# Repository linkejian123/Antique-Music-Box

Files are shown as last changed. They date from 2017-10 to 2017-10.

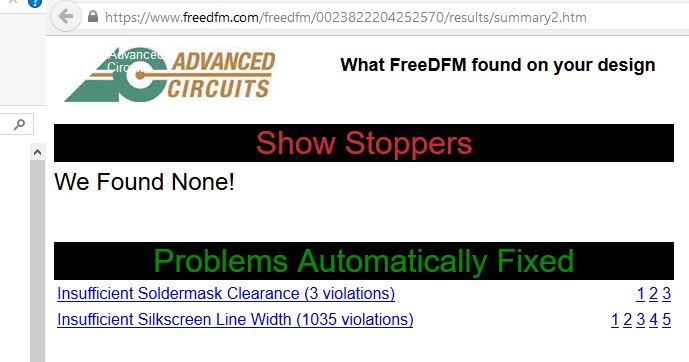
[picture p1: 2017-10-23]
OBJ477/Gerbers/iv17.JPG

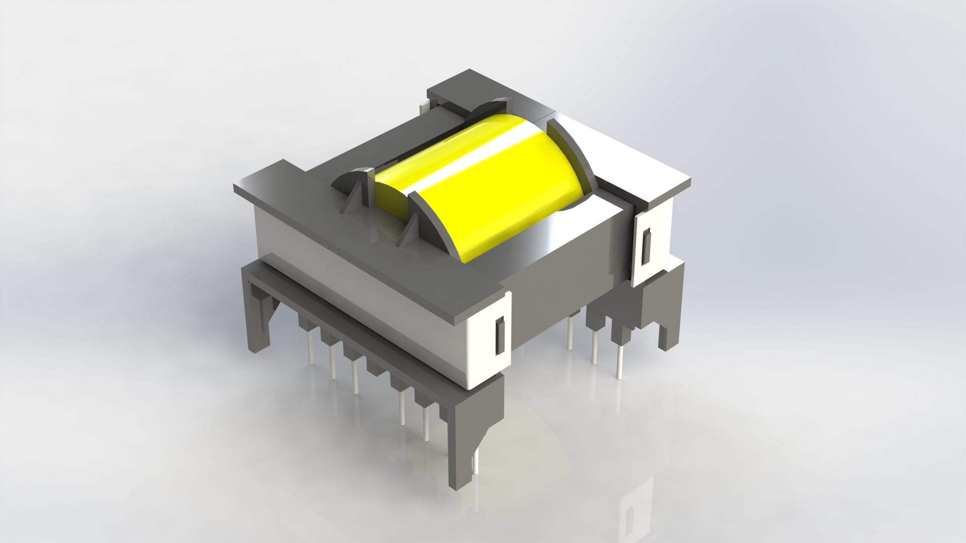
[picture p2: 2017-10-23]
CAD/etd39-transformer-horizontal-1.snapshot.6/Renderings/ETD39 Transformer (Horizontal).JPG

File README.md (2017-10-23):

# Antique-Music-Box

### Description
-This project was originally a senior design project in Purdue University ECE477. 
-This is a music player capable of playing mp3 on SD card or stream Bluetooth music from Android devices. The music box has digital amplifier and valve tube pre-amp. The display used 60s style VFD tube from Soviet era.
-The Microcontroller used is Microchips dsPIC33FJ256GP710A.
- !!!!  Demo Vidoe here:https://www.youtube.com/watch?v=YaUscYTW8Vs&t=1s

### Authors
-Kejian Lin
-Ran An
-Yixing Liu
-Zhiyi Xiang

### Repository Structure

-`main`,`mp3`,`sd`, `AntiqueMB.X` are the code for the PIC microcontroller for main, mp3 and sd card as it states.
- `multithread` is the experimental multithread code.
- `arduino` is the interface code for Arduino Uno.
- `CAD` is the conceptual SolidWorks model for the project.
- `OBJ477` is the PCB files in Eagle. 

### Warning
 #### High voltage
 #### Some hotfix are not documented, yet

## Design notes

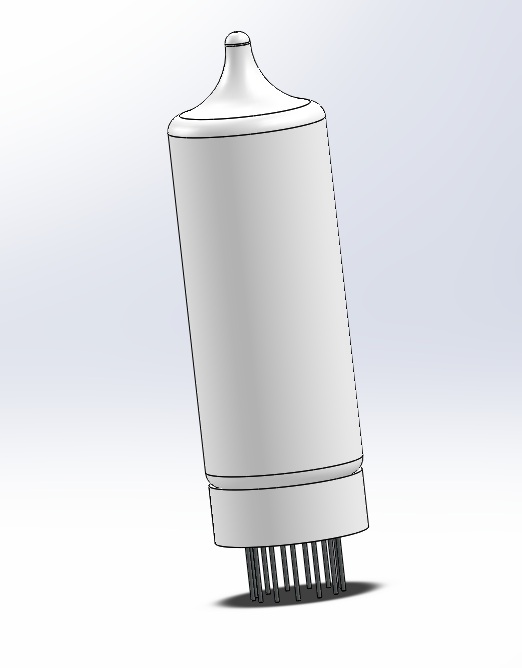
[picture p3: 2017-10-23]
CAD/em84/Renderings/IN-14.jpg

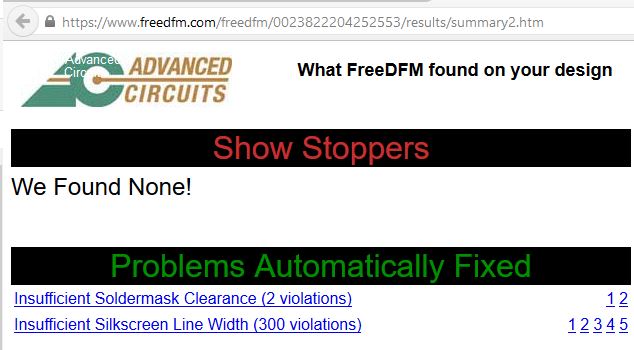
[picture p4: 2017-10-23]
OBJ477/Gerbers/hifi.JPG

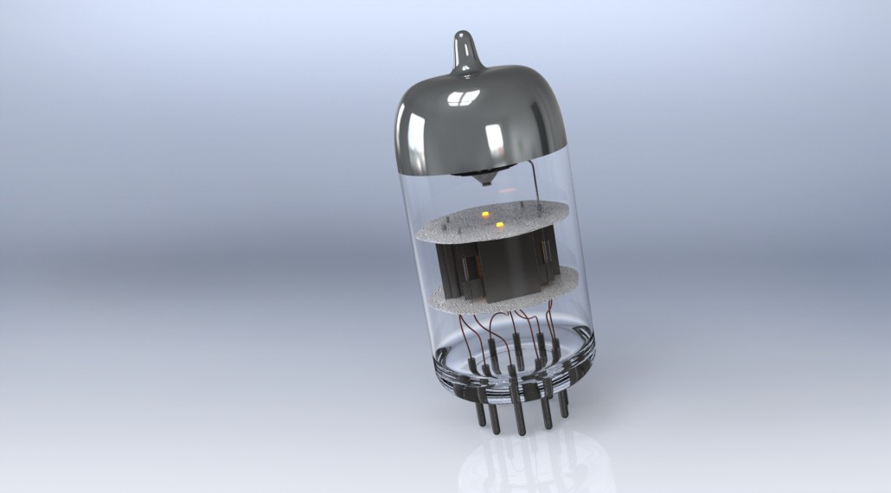
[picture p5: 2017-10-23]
CAD/ecc88/Renderings/ecc88_00220120219-29209-4jer0m.JPG

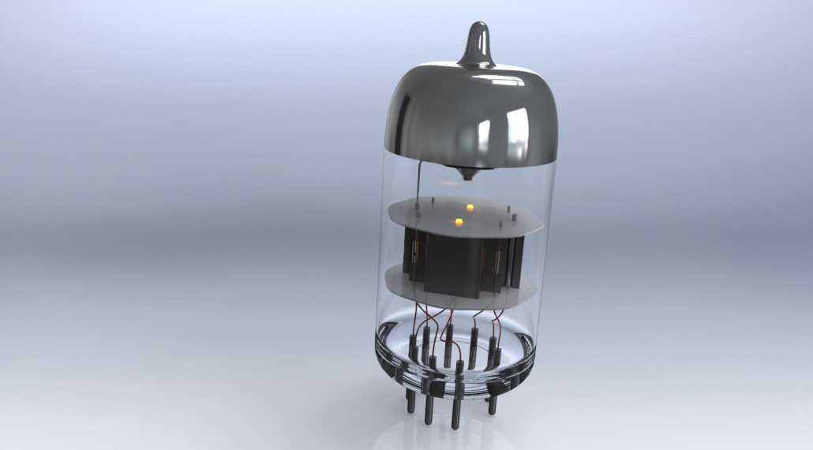
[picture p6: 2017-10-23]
CAD/ecc88/Renderings/ecc88_00120120219-28439-1ot95d6.JPG

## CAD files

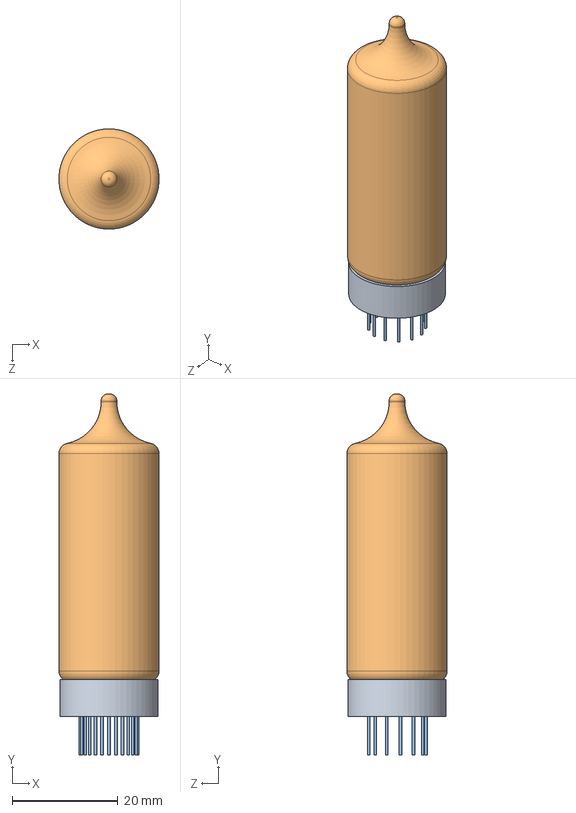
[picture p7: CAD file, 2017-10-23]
CAD/iv-17/IN-14.SLDASM
19.0 x 68.4 x 19.0 mm
pcb_standoff
tube_body
tube_leads
flip

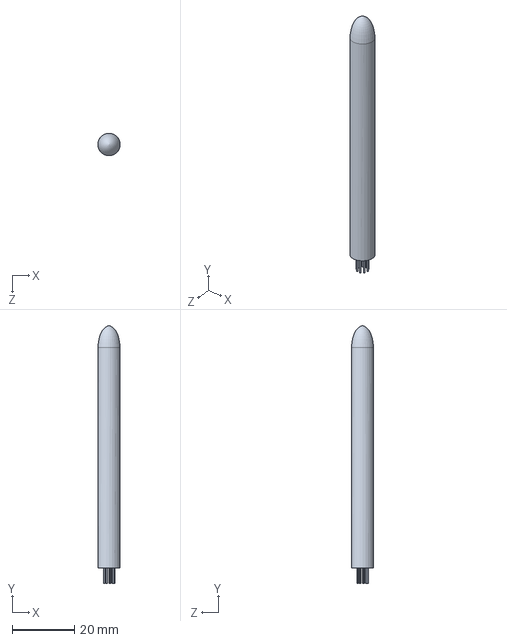
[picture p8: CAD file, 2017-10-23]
CAD/iv-25/vfdbartube.SLDASM
7.20 x 83.0 x 7.20 mm
iv-25
insole

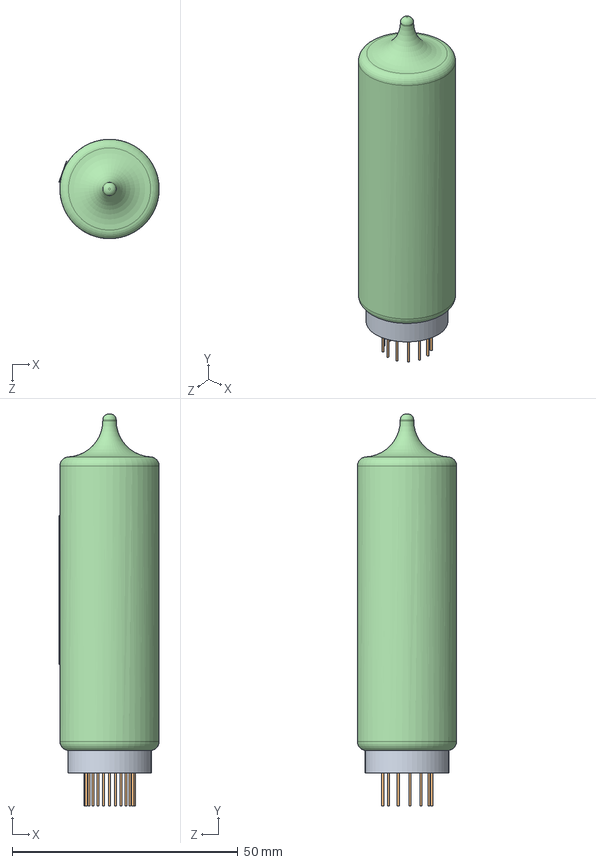
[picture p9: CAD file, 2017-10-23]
CAD/em84/em84.SLDASM
22.2 x 86.8 x 22.0 mm
pcb_standoff
tube_leads
tiepian
tube_body2

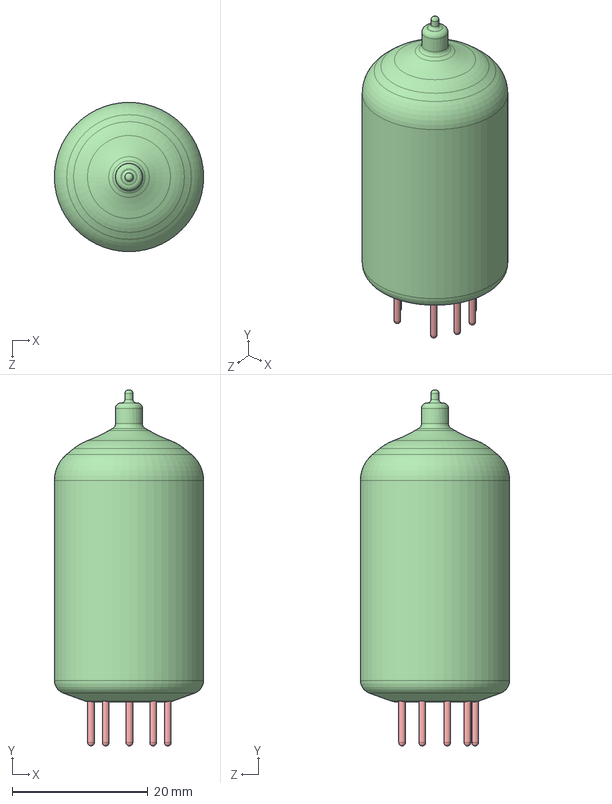
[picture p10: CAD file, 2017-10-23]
CAD/msc/12ax7/12ax7_complete.SLDASM
22.0 x 52.5 x 22.0 mm
mica3_lower
cathode x 2
grid x 2
grid wire x 120
cathode_end x 4
anode x 4
sheild
mica2
support_pin x 4
top_mica
boat
12ax7_glass
pins

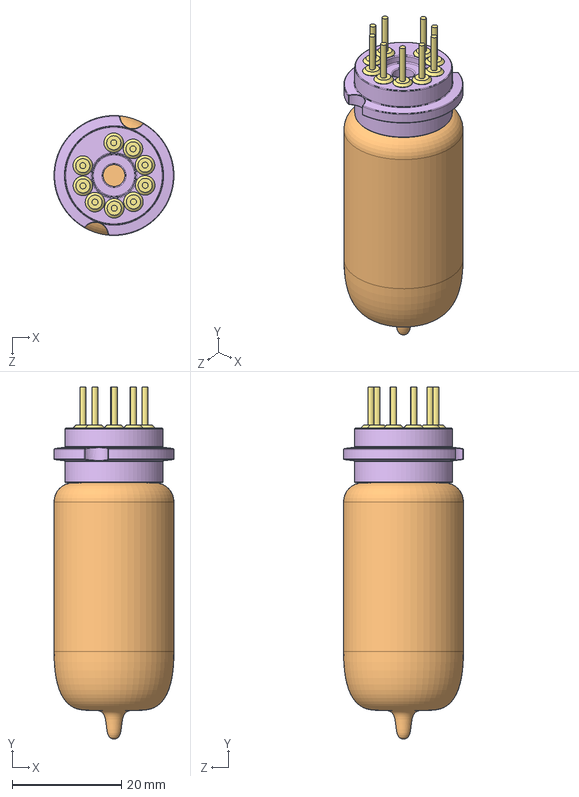
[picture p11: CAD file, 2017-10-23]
CAD/ecc88/ecc88/ECC88.SLDASM
22.0 x 64.5 x 22.0 mm
ecc88_pins
ecc88_balon
ecc88_insulator x 2
ecc88_reflector
ecc88_heater
noval ceramic body
Noval pin x 9

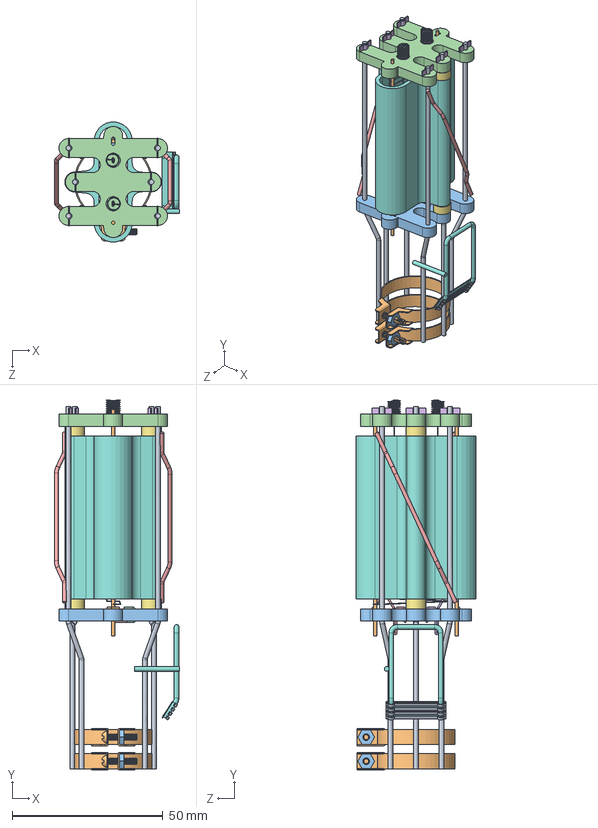
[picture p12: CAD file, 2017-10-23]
CAD/msc/845/845 - INTERNALS.SLDASM
41.5 x 122.6 x 39.8 mm
845 - support rods
845 - support rod clamp x 2
845 - bottom ceramic
845 - centre cathode anchor
845 - left hand cathode anchor
845 - right hand cathode anchor
845 - top ceramic spacer x 4
845 - anode
845 - cathode
845 - grid support x 2
845 - grid wire
845 - top ceramic
845 - suppoty brace x 2
845 - retaining bit x 6
845 - cathode spring x 2
845 - boat frame
845 - boat part 2
845 - little screw x 2
845 - little nut x 2

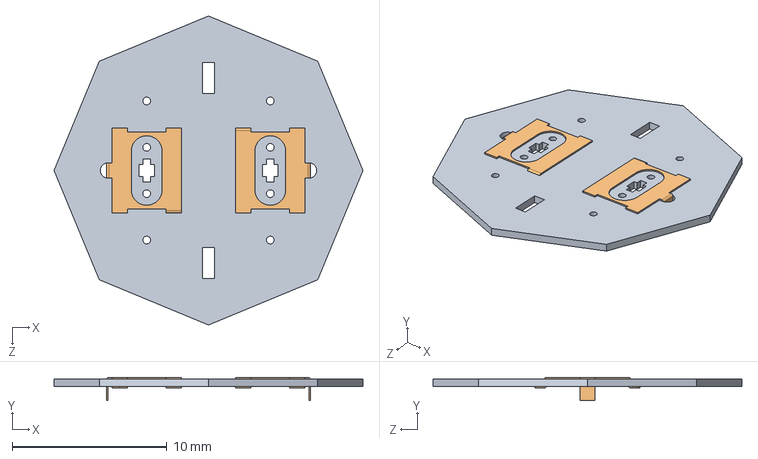
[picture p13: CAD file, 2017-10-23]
CAD/msc/12ax7/12ax7_mica_2.sldasm
20.0 x 1.50 x 20.0 mm
mica2
cathode_end x 2

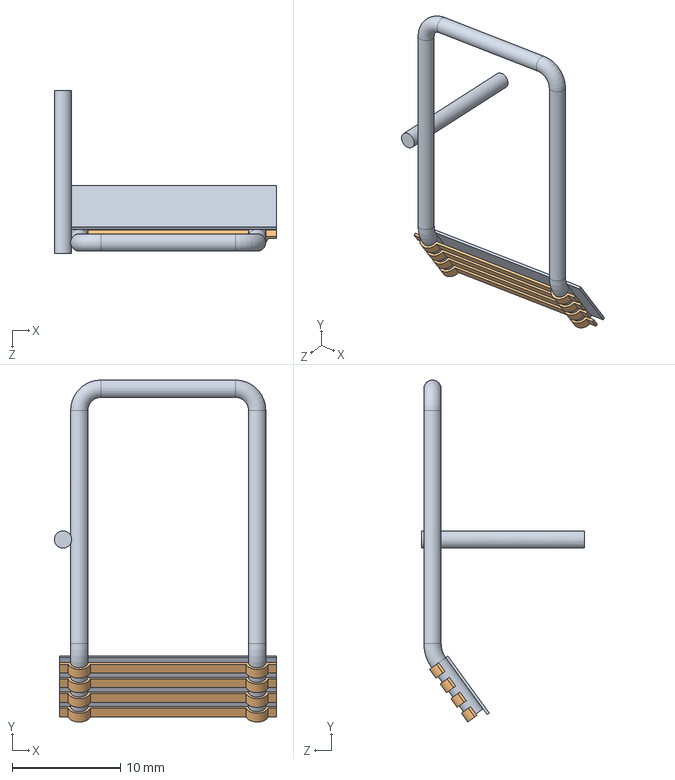
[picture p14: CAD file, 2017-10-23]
CAD/msc/845/845 - BOAT ASSEMBLY.SLDASM
20.5 x 31.5 x 15.0 mm
845 - boat frame
845 - boat part 2

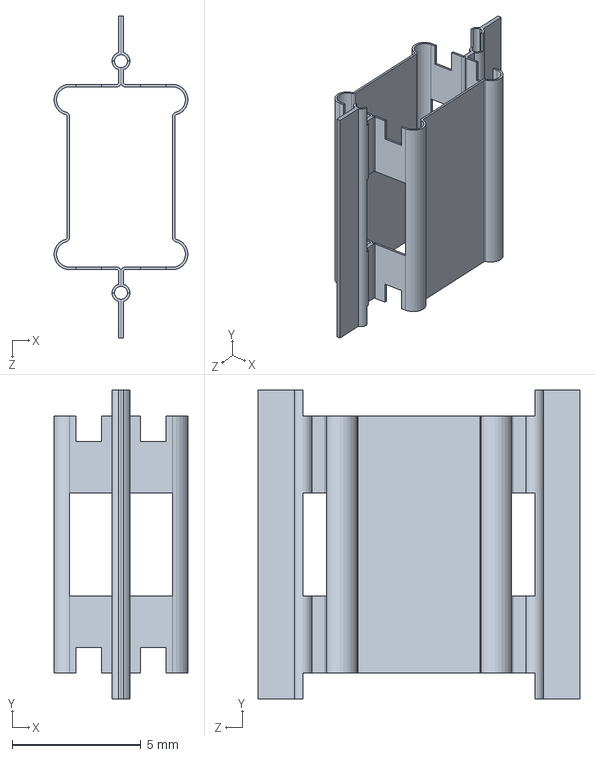
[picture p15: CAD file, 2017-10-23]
CAD/msc/12ax7/anode_assy.sldasm
5.19 x 12.0 x 12.5 mm
anode x 2

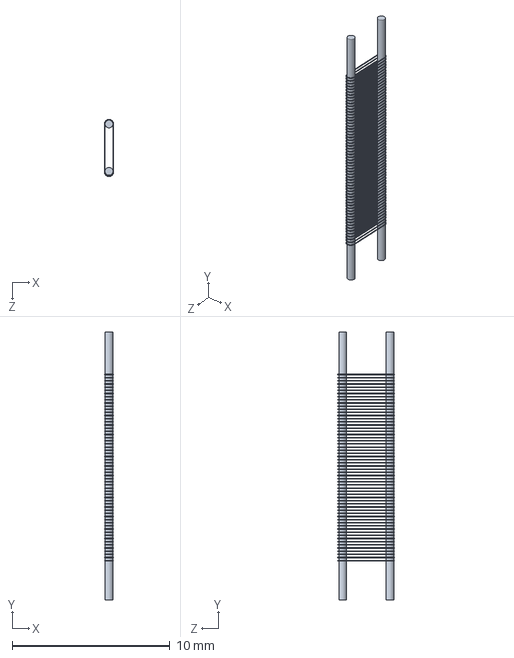
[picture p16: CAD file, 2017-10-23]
CAD/msc/12ax7/grid assembly.SLDASM
0.59 x 17.0 x 3.64 mm
grid
grid wire x 60

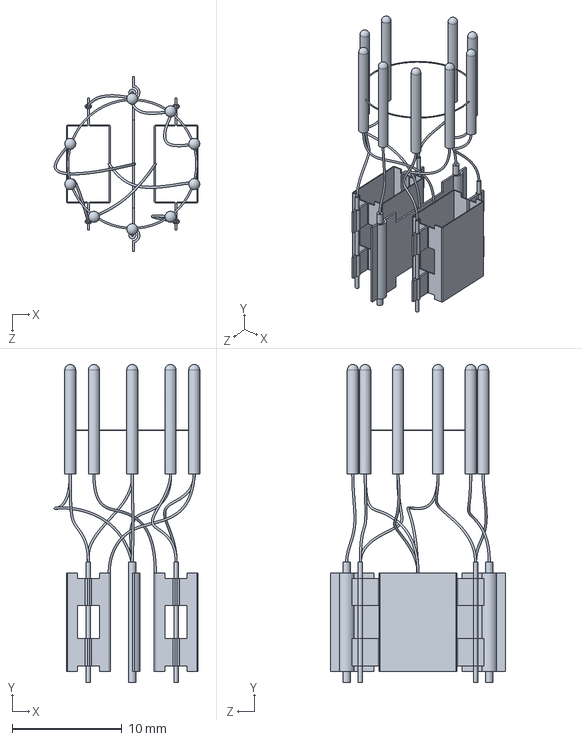
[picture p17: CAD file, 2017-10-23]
CAD/ecc88/ecc88/ecc88_pins.SLDPRT
13.3 x 29.0 x 16.0 mm

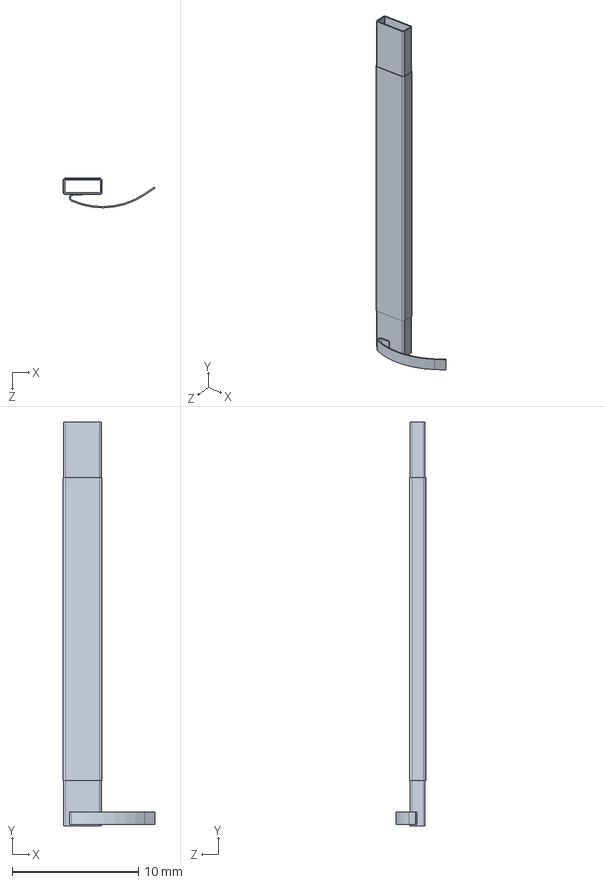
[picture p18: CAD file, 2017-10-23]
CAD/el84 sub 6z4/EL84 CATHODE.SLDPRT
7.28 x 32.0 x 2.35 mm

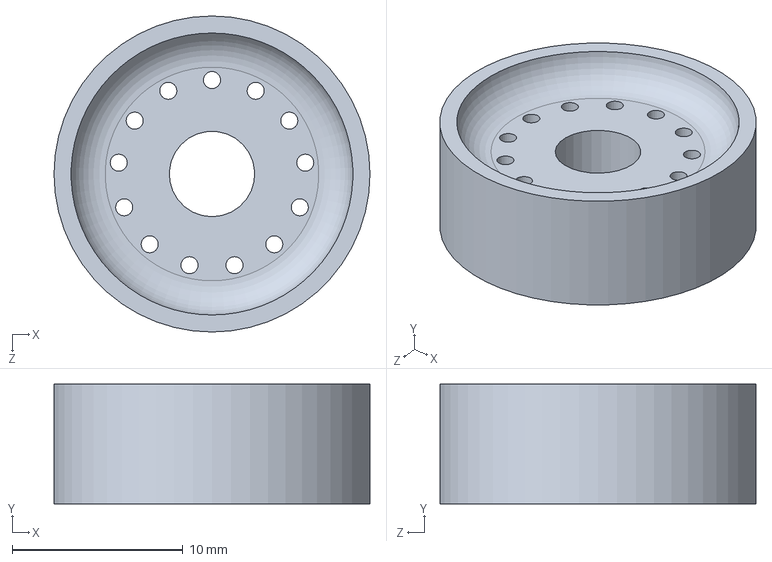
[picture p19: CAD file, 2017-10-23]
CAD/em84/pcb_standoff.SLDPRT
18.5 x 7.00 x 18.5 mm

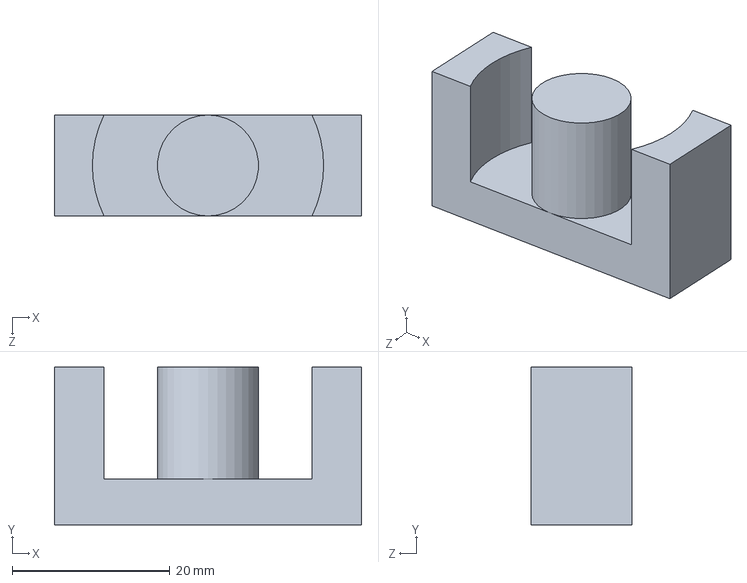
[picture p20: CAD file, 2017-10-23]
CAD/etd39-transformer-horizontal-1.snapshot.6/ETD39 Horizontal/6. Core.SLDPRT
38.9 x 20.0 x 12.8 mm

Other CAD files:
CAD/etd39-transformer-horizontal-1.snapshot.6/ETD39 Horizontal/1. ETD39 assembly.SLDASM
CAD/little-knob.snapshot.2/myknob.IGS
CAD/msc/12ax7/sheild.sldprt
CAD/msc/845/845 - cathode.SLDPRT
CAD/ecc88/ecc88/ecc88_balon.SLDPRT
CAD/ecc88/ecc88/ecc88_heater.SLDPRT
CAD/ecc88/ecc88/ecc88_insulator.SLDPRT
CAD/ecc88/ecc88/ecc88_reflector.SLDPRT
CAD/el84 sub 6z4/EL84 HEATER LEADS.SLDPRT
CAD/el84 sub 6z4/el34 suppressor.SLDPRT
CAD/el84 sub 6z4/el84 - boat.SLDPRT
CAD/el84 sub 6z4/el84 - spring thing.SLDPRT
CAD/el84 sub 6z4/el84 - top shield.SLDPRT
CAD/el84 sub 6z4/el84 glass.SLDPRT
CAD/el84 sub 6z4/el84 lower mica.SLDPRT
CAD/el84 sub 6z4/el84 pins.SLDPRT
CAD/el84 sub 6z4/el84 plate.SLDPRT
CAD/el84 sub 6z4/screen connector.SLDPRT
CAD/em84/tiepian.SLDPRT
CAD/em84/tube_body2.SLDPRT
CAD/em84/tube_leads.SLDPRT
CAD/etd39-transformer-horizontal-1.snapshot.6/ETD39 Horizontal/2. Case (center).SLDPRT
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

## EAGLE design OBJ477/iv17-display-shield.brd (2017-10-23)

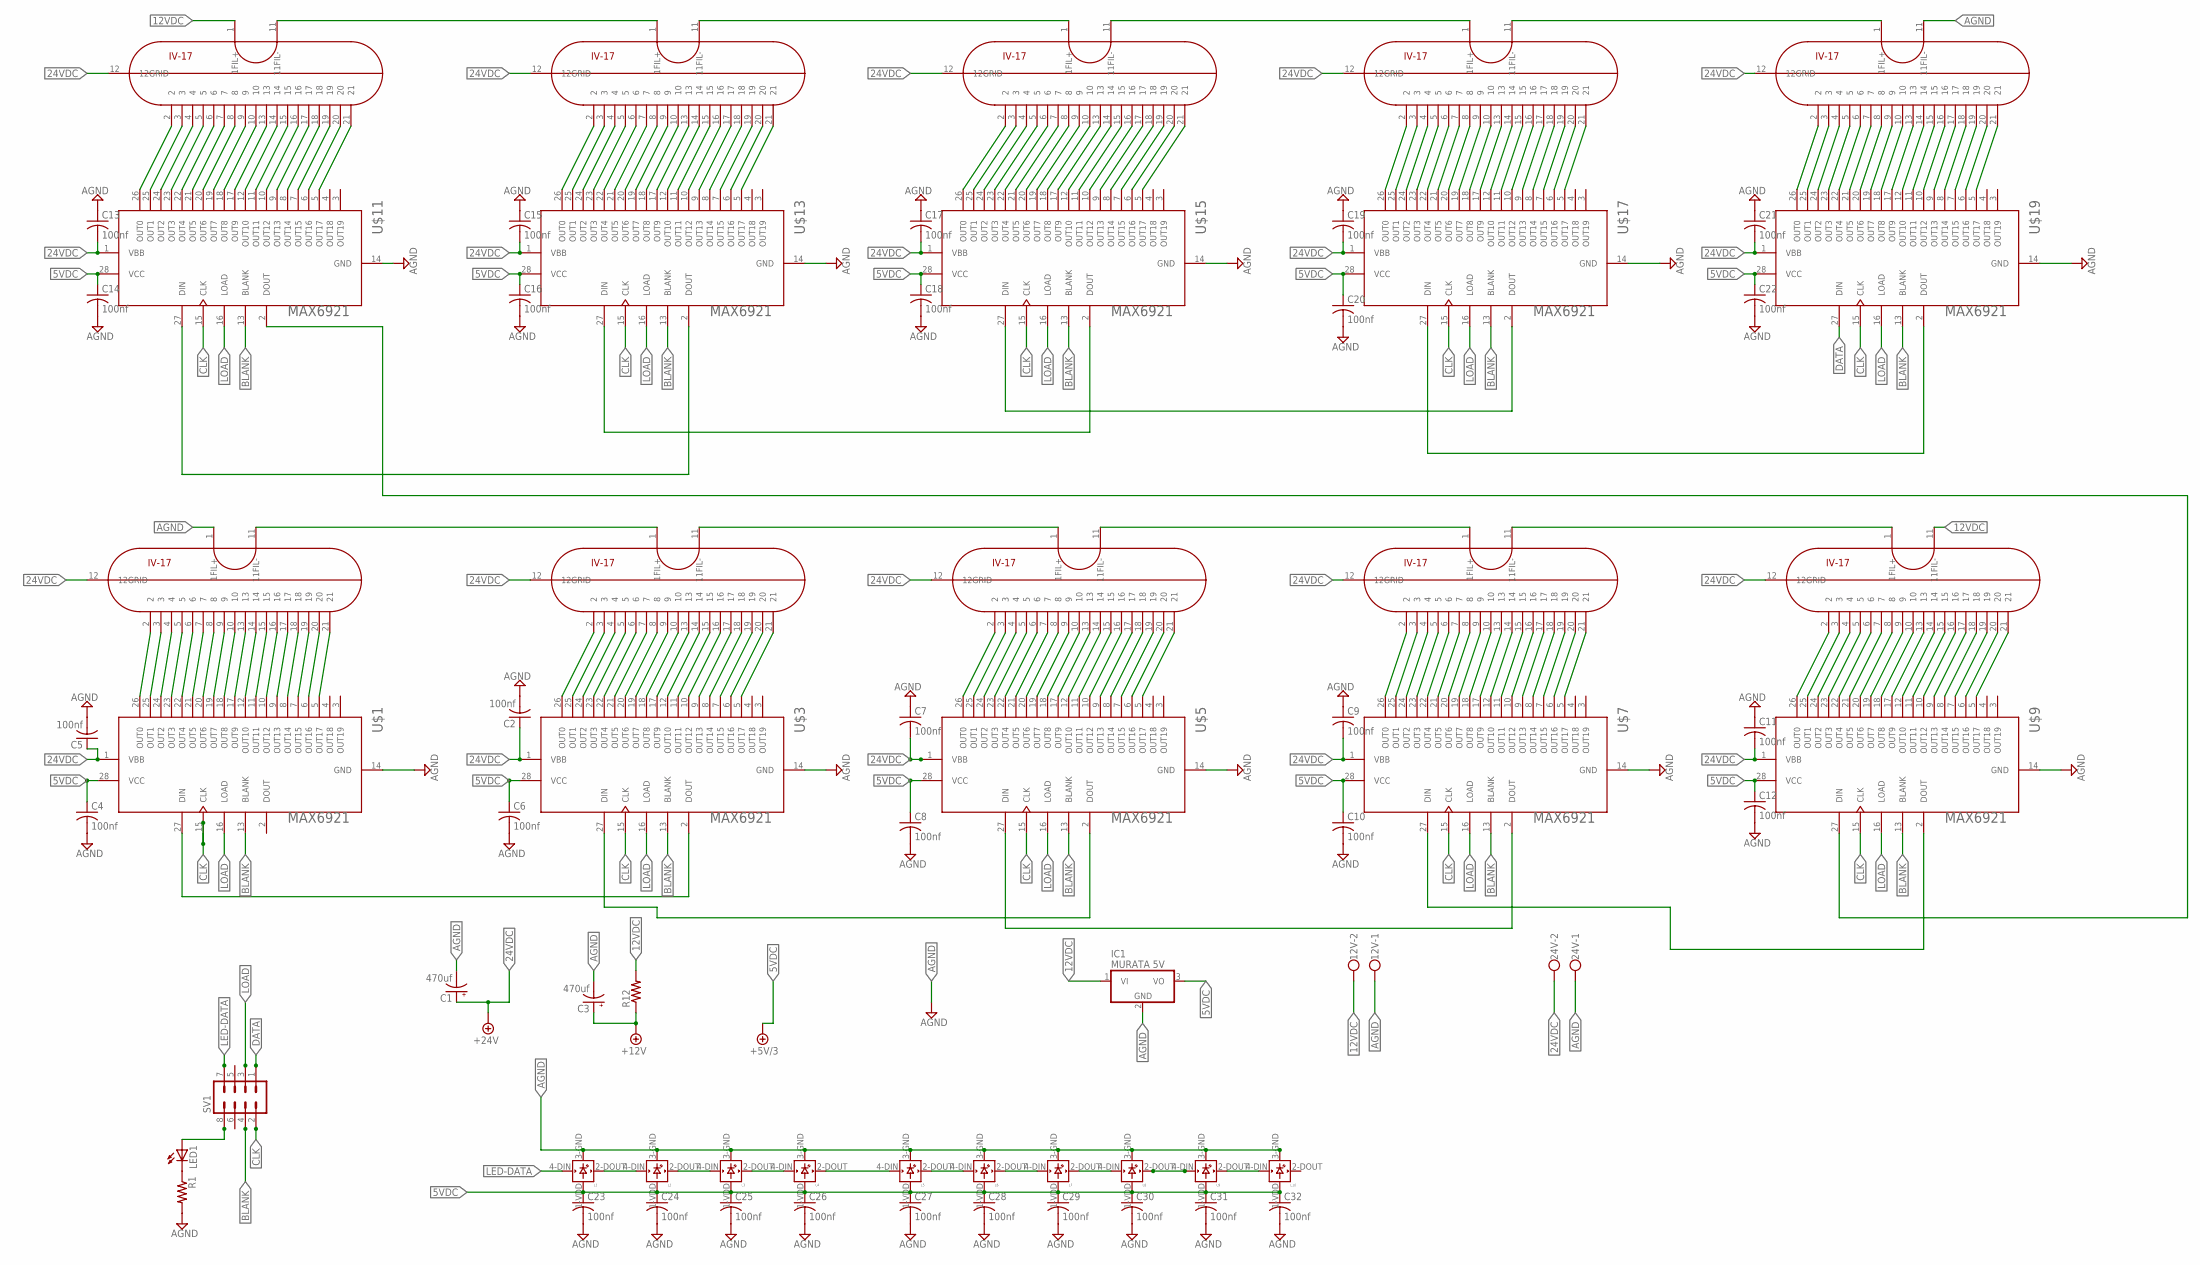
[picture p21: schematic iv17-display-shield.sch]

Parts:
12V, 24V: W237-102
C1, C3: 470uf; E5-10,5
C2, C4, C5, C6, C7, C8, C9, C10, C11, C12, C13, C14, C15, C16, C17, C18, C19, C20, C21, C22, C23, C24, C25, C26, C27, C28, C29, C30, C31, C32: 100nf; C1206
IC1: MURATA 5V; TO220V
L1, L2, L3, L4, L5, L6, L7, L8, L9, L10: WS2812B
LED1: LEDSMT1206; 1206
R1: R-US_R1206; R1206
R12: R-US_0207/10; 0207/10
SV1: MA04-2
U$1, U$3, U$5, U$7, U$9, U$11, U$13, U$15, U$17, U$19: MAX6921; SOIC-28W
U$2, U$4, U$6, U$8, U$10, U$12, U$14, U$16, U$18, U$20: IV17; NIXIE-22

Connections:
5VDC: C4.1, C6.1, C8.1, C10.1, C12.1, C14.1, C16.1, C18.1, C20.1, C22.1, C23.1, C24.1, C25.1, C26.1, C27.1, C28.1, C29.1, C30.1, C31.1, C32.1, IC1.3 (VO), L1.1-VDD (VDD), L2.1-VDD (VDD), L3.1-VDD (VDD), L4.1-VDD (VDD), L5.1-VDD (VDD), L6.1-VDD (VDD), L7.1-VDD (VDD), L8.1-VDD (VDD), L9.1-VDD (VDD), L10.1-VDD (VDD), U$1.28 (VCC), U$3.28 (VCC), U$5.28 (VCC), U$7.28 (VCC), U$9.28 (VCC), U$11.28 (VCC), U$13.28 (VCC), U$15.28 (VCC), U$17.28 (VCC), U$19.28 (VCC)
12VDC: 12V.2, IC1.1 (VI), R12.2, U$10.11 (11FIL-), U$12.1 (1FIL+)
24VDC: 24V.2, C1.+, C2.1, C5.1, C7.2, C9.2, C11.2, C13.2, C15.2, C17.2, C19.2, C21.2, U$1.1 (VBB), U$2.12 (12GRID), U$3.1 (VBB), U$4.12 (12GRID), U$5.1 (VBB), U$6.12 (12GRID), U$7.1 (VBB), U$8.12 (12GRID), U$9.1 (VBB), U$10.12 (12GRID), U$11.1 (VBB), U$12.12 (12GRID), U$13.1 (VBB), U$14.12 (12GRID), U$15.1 (VBB), U$16.12 (12GRID), U$17.1 (VBB), U$18.12 (12GRID), U$19.1 (VBB), U$20.12 (12GRID)
+12V: C3.+, R12.1
AGND: 12V.1, 24V.1, C1.-, C2.2, C3.-, C4.2, C5.2, C6.2, C7.1, C8.2, C9.1, C10.2, C11.1, C12.2, C13.1, C14.2, C15.1, C16.2, C17.1, C18.2, C19.1, C20.2, C21.1, C22.2, C23.2, C24.2, C25.2, C26.2, C27.2, C28.2, C29.2, C30.2, C31.2, C32.2, IC1.2 (GND), L1.3-GND (GND), L2.3-GND (GND), L3.3-GND (GND), L4.3-GND (GND), L5.3-GND (GND), L6.3-GND (GND), L7.3-GND (GND), L8.3-GND (GND), L9.3-GND (GND), L10.3-GND (GND), R1.2, U$1.14 (GND), U$2.1 (1FIL+), U$3.14 (GND), U$5.14 (GND), U$7.14 (GND), U$9.14 (GND), U$11.14 (GND), U$13.14 (GND), U$15.14 (GND), U$17.14 (GND), U$19.14 (GND), U$20.11 (11FIL-)
BLANK: SV1.4, U$1.13 (BLANK), U$3.13 (BLANK), U$5.13 (BLANK), U$7.13 (BLANK), U$9.13 (BLANK), U$11.13 (BLANK), U$13.13 (BLANK), U$15.13 (BLANK), U$17.13 (BLANK), U$19.13 (BLANK)
CLK: SV1.2, U$1.15 (CLK), U$3.15 (CLK), U$5.15 (CLK), U$7.15 (CLK), U$9.15 (CLK), U$11.15 (CLK), U$13.15 (CLK), U$15.15 (CLK), U$17.15 (CLK), U$19.15 (CLK)
DATA: SV1.1, U$19.27 (DIN)
LED-DATA: L1.4-DIN (DIN), SV1.7
LOAD: SV1.3, U$1.16 (LOAD), U$3.16 (LOAD), U$5.16 (LOAD), U$7.16 (LOAD), U$9.16 (LOAD), U$11.16 (LOAD), U$13.16 (LOAD), U$15.16 (LOAD), U$17.16 (LOAD), U$19.16 (LOAD)
unnamed: U$1.26 (OUT0), U$2.2
unnamed: U$1.25 (OUT1), U$2.3
unnamed: U$1.24 (OUT2), U$2.4
unnamed: U$1.23 (OUT3), U$2.5
unnamed: U$1.22 (OUT4), U$2.6
unnamed: U$1.21 (OUT5), U$2.7
unnamed: U$1.20 (OUT6), U$2.8
unnamed: U$1.19 (OUT7), U$2.9
unnamed: U$1.18 (OUT8), U$2.10
unnamed: U$1.17 (OUT9), U$2.13
unnamed: U$1.12 (OUT10), U$2.14
unnamed: U$1.11 (OUT11), U$2.15
unnamed: U$1.10 (OUT12), U$2.16
unnamed: U$1.9 (OUT13), U$2.17
unnamed: U$1.8 (OUT14), U$2.18
unnamed: U$1.7 (OUT15), U$2.19
unnamed: U$1.6 (OUT16), U$2.20
unnamed: U$1.5 (OUT17), U$2.21
unnamed: U$3.26 (OUT0), U$4.2
unnamed: U$3.25 (OUT1), U$4.3
unnamed: U$3.24 (OUT2), U$4.4
unnamed: U$3.23 (OUT3), U$4.5
unnamed: U$17.27 (DIN), U$19.2 (DOUT)
unnamed: U$3.22 (OUT4), U$4.6
unnamed: U$3.21 (OUT5), U$4.7
unnamed: U$3.20 (OUT6), U$4.8
unnamed: U$3.19 (OUT7), U$4.9
unnamed: U$3.18 (OUT8), U$4.10
unnamed: U$3.17 (OUT9), U$4.13
unnamed: U$3.12 (OUT10), U$4.14
unnamed: U$3.11 (OUT11), U$4.15
unnamed: U$3.10 (OUT12), U$4.16
unnamed: U$3.9 (OUT13), U$4.17
unnamed: U$3.8 (OUT14), U$4.18
unnamed: U$3.7 (OUT15), U$4.19
unnamed: U$3.6 (OUT16), U$4.20
unnamed: U$3.5 (OUT17), U$4.21
unnamed: U$5.26 (OUT0), U$6.2
unnamed: U$5.25 (OUT1), U$6.3
unnamed: U$5.24 (OUT2), U$6.4
unnamed: U$15.27 (DIN), U$17.2 (DOUT)
unnamed: U$5.23 (OUT3), U$6.5
unnamed: U$5.22 (OUT4), U$6.6
unnamed: U$5.21 (OUT5), U$6.7
unnamed: U$5.20 (OUT6), U$6.8
unnamed: U$5.19 (OUT7), U$6.9
unnamed: U$5.18 (OUT8), U$6.10
unnamed: U$5.17 (OUT9), U$6.13
unnamed: U$5.12 (OUT10), U$6.14
unnamed: U$5.11 (OUT11), U$6.15
unnamed: U$5.10 (OUT12), U$6.16
unnamed: U$5.9 (OUT13), U$6.17
unnamed: U$5.8 (OUT14), U$6.18
unnamed: U$5.7 (OUT15), U$6.19
unnamed: U$5.6 (OUT16), U$6.20
unnamed: U$5.5 (OUT17), U$6.21
unnamed: U$7.26 (OUT0), U$8.2
unnamed: U$7.25 (OUT1), U$8.3
unnamed: U$7.24 (OUT2), U$8.4
unnamed: U$7.23 (OUT3), U$8.5
unnamed: U$7.22 (OUT4), U$8.6
unnamed: U$7.21 (OUT5), U$8.7
unnamed: U$11.27 (DIN), U$13.2 (DOUT)
unnamed: U$7.20 (OUT6), U$8.8
unnamed: U$7.19 (OUT7), U$8.9
unnamed: U$7.18 (OUT8), U$8.10
unnamed: U$7.17 (OUT9), U$8.13
unnamed: U$7.12 (OUT10), U$8.14
unnamed: U$7.11 (OUT11), U$8.15
unnamed: U$7.10 (OUT12), U$8.16
unnamed: U$7.9 (OUT13), U$8.17
unnamed: U$7.8 (OUT14), U$8.18
unnamed: U$7.7 (OUT15), U$8.19
unnamed: U$7.6 (OUT16), U$8.20
unnamed: U$7.5 (OUT17), U$8.21
unnamed: U$9.26 (OUT0), U$10.2
unnamed: U$9.25 (OUT1), U$10.3
unnamed: U$9.24 (OUT2), U$10.4
unnamed: U$9.23 (OUT3), U$10.5
unnamed: U$9.22 (OUT4), U$10.6
unnamed: U$9.21 (OUT5), U$10.7
unnamed: U$9.20 (OUT6), U$10.8
unnamed: U$9.19 (OUT7), U$10.9
unnamed: U$9.18 (OUT8), U$10.10
unnamed: U$9.27 (DIN), U$11.2 (DOUT)
unnamed: U$9.17 (OUT9), U$10.13
unnamed: U$9.12 (OUT10), U$10.14
unnamed: U$9.11 (OUT11), U$10.15
unnamed: U$9.10 (OUT12), U$10.16
unnamed: U$9.9 (OUT13), U$10.17
unnamed: U$9.8 (OUT14), U$10.18
unnamed: U$9.7 (OUT15), U$10.19
unnamed: U$9.6 (OUT16), U$10.20
unnamed: U$9.5 (OUT17), U$10.21
unnamed: U$11.26 (OUT0), U$12.2
unnamed: U$11.25 (OUT1), U$12.3
unnamed: U$11.24 (OUT2), U$12.4
unnamed: U$11.23 (OUT3), U$12.5
unnamed: U$11.22 (OUT4), U$12.6
unnamed: U$11.21 (OUT5), U$12.7
unnamed: U$11.20 (OUT6), U$12.8
unnamed: U$11.19 (OUT7), U$12.9
unnamed: U$11.18 (OUT8), U$12.10
unnamed: U$11.17 (OUT9), U$12.13
unnamed: U$11.12 (OUT10), U$12.14
unnamed: U$11.11 (OUT11), U$12.15
unnamed: U$7.27 (DIN), U$9.2 (DOUT)
unnamed: U$11.10 (OUT12), U$12.16
unnamed: L1.2-DOUT (DOUT), L2.4-DIN (DIN)
unnamed: L2.2-DOUT (DOUT), L3.4-DIN (DIN)
unnamed: U$8.11 (11FIL-), U$10.1 (1FIL+)
unnamed: U$6.11 (11FIL-), U$8.1 (1FIL+)
unnamed: U$4.11 (11FIL-), U$6.1 (1FIL+)
unnamed: U$2.11 (11FIL-), U$4.1 (1FIL+)
unnamed: U$11.9 (OUT13), U$12.17
unnamed: U$11.8 (OUT14), U$12.18
unnamed: U$11.7 (OUT15), U$12.19
unnamed: U$11.6 (OUT16), U$12.20
unnamed: U$11.5 (OUT17), U$12.21
unnamed: U$13.26 (OUT0), U$14.2
unnamed: U$13.25 (OUT1), U$14.3
unnamed: U$13.24 (OUT2), U$14.4
unnamed: U$13.23 (OUT3), U$14.5
unnamed: U$13.22 (OUT4), U$14.6
unnamed: U$13.21 (OUT5), U$14.7
unnamed: U$13.20 (OUT6), U$14.8
unnamed: U$13.19 (OUT7), U$14.9
unnamed: U$13.18 (OUT8), U$14.10
unnamed: U$13.17 (OUT9), U$14.13
unnamed: U$13.12 (OUT10), U$14.14
unnamed: U$13.11 (OUT11), U$14.15
unnamed: U$13.10 (OUT12), U$14.16
unnamed: U$5.27 (DIN), U$7.2 (DOUT)
unnamed: U$13.9 (OUT13), U$14.17
unnamed: L3.2-DOUT (DOUT), L4.4-DIN (DIN)
unnamed: U$13.8 (OUT14), U$14.18
unnamed: U$13.7 (OUT15), U$14.19
unnamed: U$13.6 (OUT16), U$14.20
unnamed: U$13.5 (OUT17), U$14.21
unnamed: U$15.26 (OUT0), U$16.2
unnamed: U$15.25 (OUT1), U$16.3
unnamed: U$15.24 (OUT2), U$16.4
unnamed: U$15.23 (OUT3), U$16.5
unnamed: U$15.22 (OUT4), U$16.6
unnamed: U$15.21 (OUT5), U$16.7
unnamed: U$15.20 (OUT6), U$16.8
unnamed: U$15.19 (OUT7), U$16.9
unnamed: U$15.18 (OUT8), U$16.10
unnamed: U$15.17 (OUT9), U$16.13
unnamed: U$15.12 (OUT10), U$16.14
unnamed: U$15.11 (OUT11), U$16.15
unnamed: U$15.10 (OUT12), U$16.16
unnamed: U$15.9 (OUT13), U$16.17
unnamed: U$15.8 (OUT14), U$16.18
unnamed: U$3.27 (DIN), U$5.2 (DOUT)
unnamed: U$15.7 (OUT15), U$16.19
unnamed: L4.2-DOUT (DOUT), L5.4-DIN (DIN)
unnamed: L5.2-DOUT (DOUT), L6.4-DIN (DIN)
unnamed: U$15.6 (OUT16), U$16.20
unnamed: U$15.5 (OUT17), U$16.21
unnamed: U$17.26 (OUT0), U$18.2
unnamed: U$17.25 (OUT1), U$18.3
unnamed: U$17.24 (OUT2), U$18.4
unnamed: U$17.23 (OUT3), U$18.5
unnamed: U$17.22 (OUT4), U$18.6
unnamed: U$17.21 (OUT5), U$18.7
unnamed: U$17.20 (OUT6), U$18.8
unnamed: U$17.19 (OUT7), U$18.9
unnamed: U$17.18 (OUT8), U$18.10
unnamed: U$17.17 (OUT9), U$18.13
unnamed: U$17.12 (OUT10), U$18.14
unnamed: U$17.11 (OUT11), U$18.15
unnamed: U$17.10 (OUT12), U$18.16
unnamed: U$17.9 (OUT13), U$18.17
unnamed: U$17.8 (OUT14), U$18.18
unnamed: U$17.7 (OUT15), U$18.19
unnamed: U$13.27 (DIN), U$15.2 (DOUT)
unnamed: U$17.6 (OUT16), U$18.20
unnamed: L6.2-DOUT (DOUT), L7.4-DIN (DIN)
unnamed: L7.2-DOUT (DOUT), L8.4-DIN (DIN)
unnamed: U$17.5 (OUT17), U$18.21
unnamed: U$19.26 (OUT0), U$20.2
unnamed: U$19.25 (OUT1), U$20.3
unnamed: U$19.24 (OUT2), U$20.4
unnamed: U$19.23 (OUT3), U$20.5
unnamed: U$19.22 (OUT4), U$20.6
unnamed: U$19.21 (OUT5), U$20.7
unnamed: U$19.20 (OUT6), U$20.8
unnamed: U$19.19 (OUT7), U$20.9
unnamed: U$19.18 (OUT8), U$20.10
unnamed: U$19.17 (OUT9), U$20.13
unnamed: U$19.12 (OUT10), U$20.14
unnamed: U$19.11 (OUT11), U$20.15
unnamed: U$19.10 (OUT12), U$20.16
unnamed: U$19.9 (OUT13), U$20.17
unnamed: U$19.8 (OUT14), U$20.18
unnamed: U$19.7 (OUT15), U$20.19
unnamed: U$19.6 (OUT16), U$20.20
unnamed: U$1.27 (DIN), U$3.2 (DOUT)
unnamed: U$19.5 (OUT17), U$20.21
unnamed: L8.2-DOUT (DOUT), L9.4-DIN (DIN)
unnamed: L9.2-DOUT (DOUT), L10.4-DIN (DIN)
unnamed: LED1.C, R1.1
unnamed: LED1.A, SV1.8
unnamed: U$18.11 (11FIL-), U$20.1 (1FIL+)
unnamed: U$16.11 (11FIL-), U$18.1 (1FIL+)
unnamed: U$14.11 (11FIL-), U$16.1 (1FIL+)
unnamed: U$12.11 (11FIL-), U$14.1 (1FIL+)

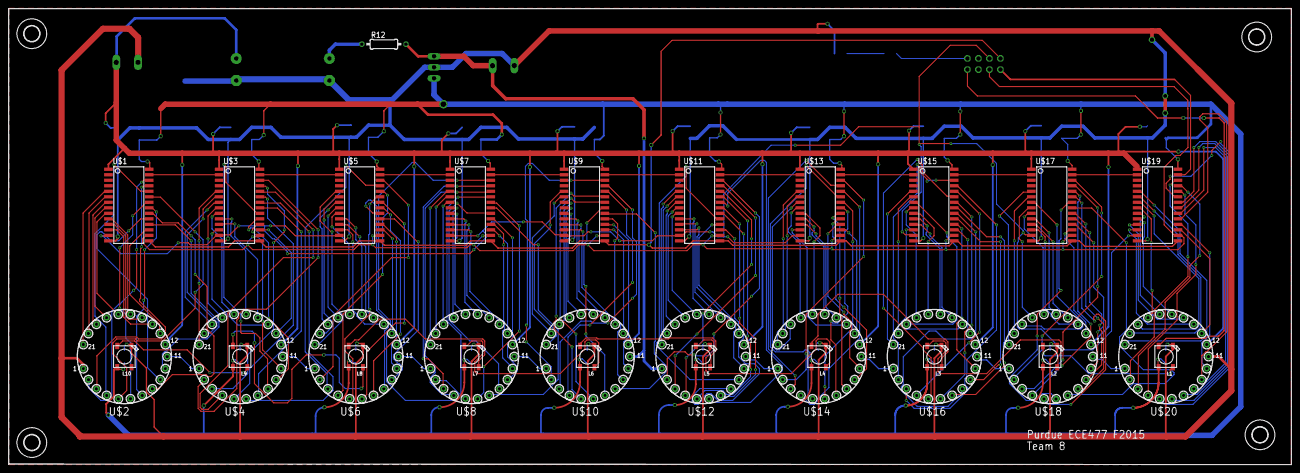
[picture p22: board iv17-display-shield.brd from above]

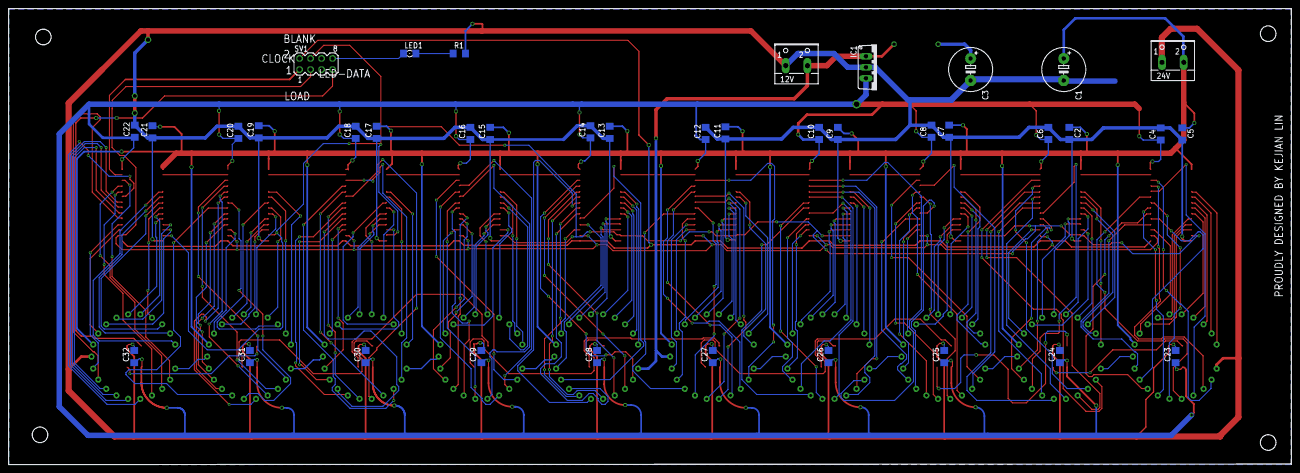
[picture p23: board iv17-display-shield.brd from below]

Board: 2 copper layers, 295.6 x 105.1 mm, 73 parts (38 on the bottom side), 218 nets.

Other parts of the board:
U$21, U$22, U$23, U$24: 3,6

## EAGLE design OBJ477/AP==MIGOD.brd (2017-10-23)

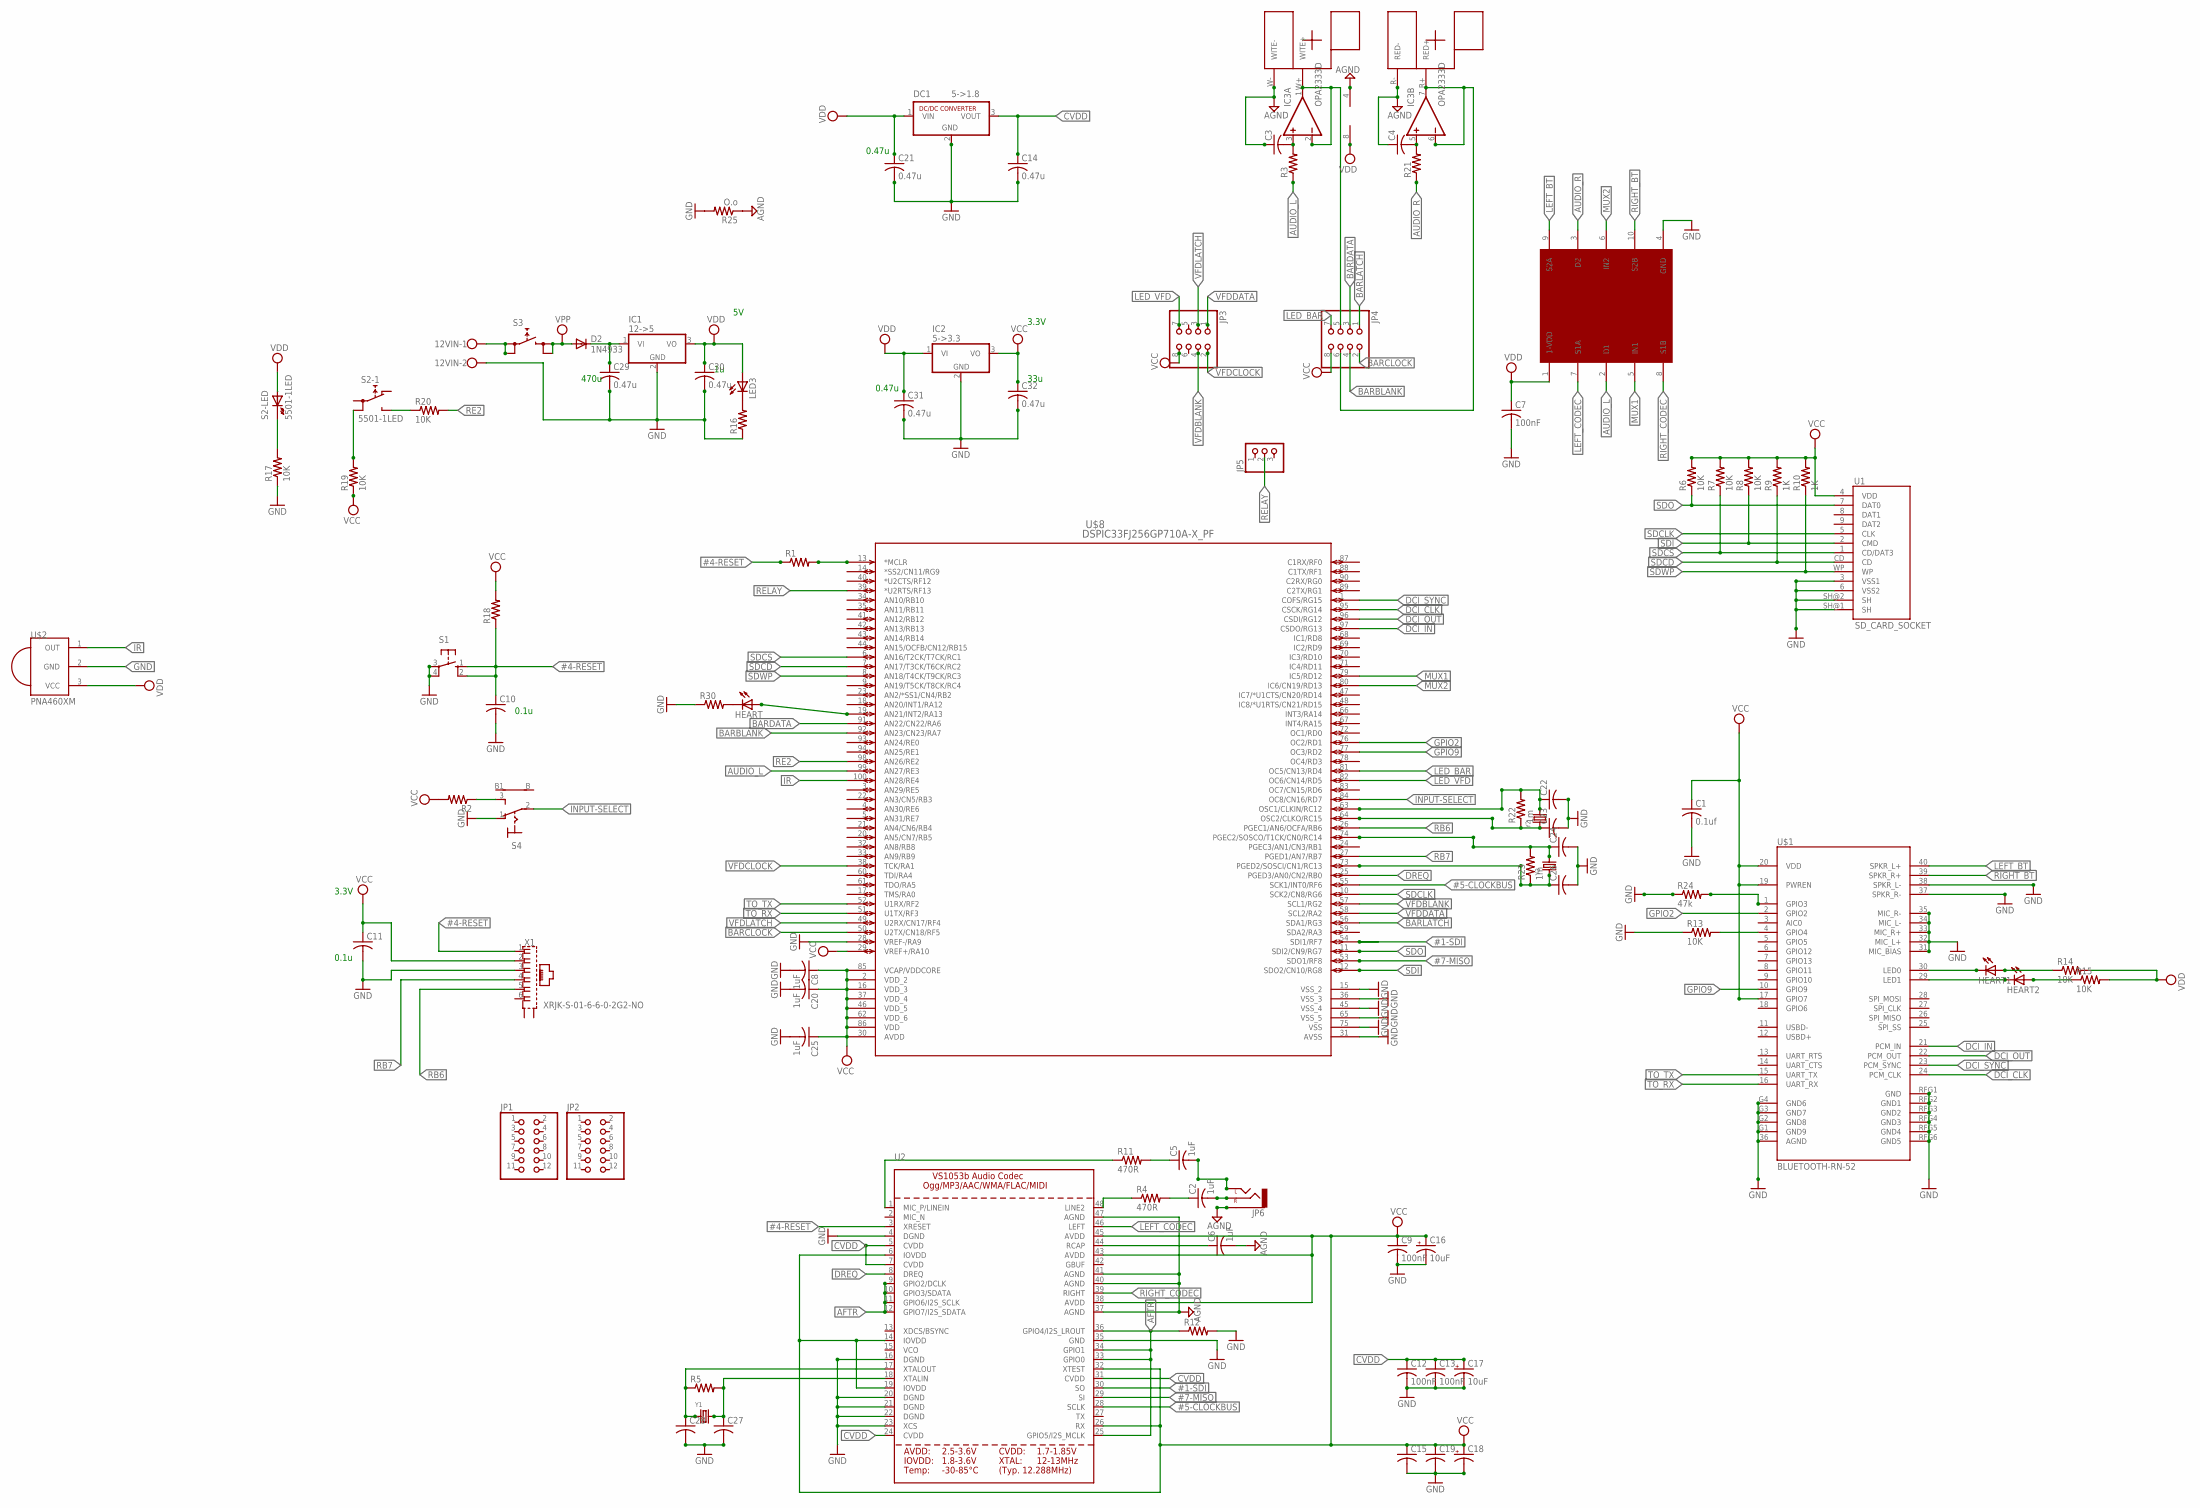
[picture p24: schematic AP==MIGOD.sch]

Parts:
12VIN: W237-102
C1: 0.1uf; C1206
C2, C5, C6, C8, C20, C25: 1uF; C1206
C3, C4: C-US050-030X075; C050-030X075
C7, C9, C12, C13: 100nF; C1206
C10, C11, C15, C19, C22, C23, C24, C26, C27, C28: C-USC1206; C1206
C14, C21, C29, C30, C31, C32: 0.47u; C1206
C16, C17: 10uF; E5-8,5
C18: CPOL-USE5-8.5; E5-8,5
D2: 1N4933; DO41-10
DC1: 5->1.8; SIP3
HEART, HEART1, HEART2: LEDSMT1206; 1206
IC1: 12->5; TO220V
IC2: 5->3.3; TO220V
IC3: OPA2333D; SO08
JP1, JP2: PINHD-2X6; 2X06
JP3, JP4: PINHD-2X4; 2X04
JP5: PINHD-1X3; 1X03
JP6: AUDIO-JACKPTH; AUDIO-JACK
LED3: LEDSMT1206; 1206
R1, R2, R5, R12, R16, R18, R30: R-US_R1206; R1206
R3, R21: R-US_0207/10; 0207/10
R4, R11: 470R; R1206
R6, R7, R8, R13, R14, R15, R17, R19, R20: 10K; R1206
R9, R10: 1K; R1206
R22, R23: 1m; R1206
R24: 47k; R1206
R25: O.o; R1206
S1: 10-XX; B3F-10XX
S2: 5501-1LED
S3: REKN
S4: 9070-1W
U1: SD_CARD_SOCKET; SD_1:1
U2: VS1053B; LQFP48
U$1: BLUETOOTH-RN-52; RN-52
U$2: PNA460XM
U$8: DSPIC33FJ256GP710A-X_PF; TQFP100_14X14MC
U$13: RCANEW; RCA
U$15: ADG884; MSOP10
X1: XRJK-S-01-6-6-0-2G2-NO
Y1, Y2, Y3: CRYSTALTHIN; CRYSTAL_3.2X2.5

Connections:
#1-SDI: U2.30 (SO), U$8.54 (SDI1/RF7)
#4-RESET: C10.1, R1.1, R18.1, S1.1 (S), S1.2 (S1), U2.3 (XRESET), X1.1
#5-CLOCKBUS: U2.28 (SCLK), U$8.55 (SCK1/INT0/RF6)
#7-MISO: U2.29 (SI), U$8.53 (SDO1/RF8)
AFTR: R12.1, U2.9 (GPIO2/DCLK), U2.10 (GPIO3/SDATA), U2.11 (GPIO6/I2S_SCLK), U2.12 (GPIO7/I2S_SDATA), U2.25 (GPIO5/I2S_MCLK), U2.33 (GPIO0), U2.34 (GPIO1), U2.36 (GPIO4/I2S_LROUT)
AGND: C3.1, C4.1, C6.2, IC3.4 (V-), JP6.SLEEVE, R25.1, U2.37 (AGND), U2.40 (AGND), U2.41 (AGND), U2.47 (AGND), U$13.R- (RED-), U$13.W- (WITE-)
AUDIO_L: R3.1, U$8.99 (AN27/RE3), U$15.2 (D1)
AUDIO_R: R21.1, U$15.3 (D2)
BARBLANK: JP4.4, U$8.92 (AN23/CN23/RA7)
BARCLOCK: JP4.2, U$8.50 (U2TX/CN18/RF5)
BARDATA: JP4.3, U$8.91 (AN22/CN22/RA6)
BARLATCH: JP4.1, U$8.56 (SDA1/RG3)
CVDD: C12.1, C13.1, C14.1, C17.+, DC1.3 (VOUT), U2.5 (CVDD), U2.7 (CVDD), U2.24 (CVDD), U2.31 (CVDD)
DCI_CLK: U$1.24 (PCM_CLK), U$8.95 (CSCK/RG14)
DCI_IN: U$1.21 (PCM_IN), U$8.97 (CSDO/RG13)
DCI_OUT: U$1.22 (PCM_OUT), U$8.96 (CSDI/RG12)
DCI_SYNC: U$1.23 (PCM_SYNC), U$8.1 (COFS/RG15)
DREQ: U2.8 (DREQ), U$8.25 (PGED3/AN0/CN2/RB0)
GND: 12VIN.2, C1.2, C7.2, C8.2, C9.2, C10.2, C11.2, C12.2, C13.2, C14.2, C15.2, C16.-, C17.-, C18.-, C19.2, C20.2, C21.2, C22.2, C23.2, C24.2, C25.2, C26.2, C27.2, C28.2, C29.2, C30.2, C31.2, C32.2, DC1.2 (GND), IC1.2 (GND), IC2.2 (GND), R12.2, R13.1, R16.1, R17.1, R24.1, R25.2, R30.1, S1.3, S1.4 (P1), S4.1 (O), U1.3 (VSS1), U1.6 (VSS2), U1.SH@1 (SH), U1.SH@2 (SH), U2.4 (DGND), U2.16 (DGND), U2.20 (DGND), U2.21 (DGND), U2.22 (DGND), U2.23 (XCS), U2.35 (GND), U$1.31 (MIC_BIAS), U$1.32 (MIC_L+), U$1.33 (MIC_R+), U$1.34 (MIC_L-), U$1.35 (MIC_R-), U$1.36 (AGND), U$1.37 (SPKR_R-), U$1.38 (SPKR_L-), U$1.G1 (GND9), U$1.G2 (GND8), U$1.G3 (GND7), U$1.G4 (GND6), U$1.RFG1 (GND), U$1.RFG2 (GND1), U$1.RFG3 (GND2), U$1.RFG4 (GND3), U$1.RFG5 (GND4), U$1.RFG6 (GND5), U$2.2 (GND), U$8.15 (VSS_2), U$8.28 (VREF-/RA9), U$8.31 (AVSS), U$8.36 (VSS_3), U$8.45 (VSS_4), U$8.65 (VSS_5), U$8.75 (VSS), U$15.4 (GND), X1.3
GPIO2: U$1.2 (GPIO2), U$8.76 (OC2/RD1)
GPIO9: U$1.10 (GPIO9), U$8.77 (OC3/RD2)
INPUT-SELECT: S4.2, U$8.84 (OC8/CN16/RD7)
IR: U$2.1 (OUT), U$8.100 (AN28/RE4)
LED_BAR: JP4.7, U$8.81 (OC5/CN13/RD4)
LED_VFD: JP3.7, U$8.82 (OC6/CN14/RD5)
LEFT_BT: U$1.40 (SPKR_L+), U$15.9 (S2A)
LEFT_CODEC: U2.46 (LEFT), U$15.7 (S1A)
MUX1: U$8.79 (IC5/RD12), U$15.5 (IN1)
MUX2: U$8.80 (IC6/CN19/RD13), U$15.6 (IN2)
unnamed: C2.2, JP6.RING (RIGHT)
unnamed: R1.2, U$8.13 (*MCLR)
unnamed: LED3.C, R16.2
unnamed: C6.1, U2.44 (RCAP)
unnamed: R19.2, S2.1B
unnamed: C28.1, R5.1, U2.17 (XTALOUT), Y1.1
unnamed: C27.1, R5.2, U2.18 (XTALIN), Y1.2
unnamed: C2.1, R4.2
unnamed: R4.1, U2.48 (LINE2)
unnamed: C5.2, JP6.TIP (LEFT)
unnamed: C5.1, R11.2
unnamed: R11.1, U2.1 (MIC_P/LINEIN)
unnamed: C24.1, R23.2, U$8.74 (PGEC2/SOSCO/T1CK/CN0/RC14), Y3.2
unnamed: R13.2, U$1.4 (GPIO4)
unnamed: C29.1, D2.C, IC1.1 (VI)
unnamed: HEART1.C, U$1.30 (LED0)
unnamed: HEART2.C, U$1.29 (LED1)
unnamed: HEART1.A, R14.1
unnamed: HEART2.A, R15.1
unnamed: C22.1, R22.2, U$8.63 (OSC1/CLKIN/RC12), Y2.2
unnamed: IC3.1 (OUT), IC3.2 (-IN), JP4.5, U$13.W+ (WITE+)
unnamed: IC3.6 (-IN), IC3.7 (OUT), JP4.6, U$13.R+ (RED+)
unnamed: C3.2, IC3.3 (+IN), R3.2
unnamed: R17.2, S2.- (K)
unnamed: R20.1, S2.NO
unnamed: 12VIN.1, S3.0A (0), S3.0B (0)
unnamed: C4.2, IC3.5 (+IN), R21.2
unnamed: R2.1, S4.3 (S)
unnamed: R24.2, U$1.1 (GPIO3)
unnamed: C23.1, R22.1, U$8.64 (OSC2/CLKO/RC15), Y2.1
unnamed: C26.1, R23.1, U$8.73 (PGED2/SOSCI/CN1/RC13), Y3.1
unnamed: HEART.A, U$8.19 (AN21/INT2/RA13)
unnamed: HEART.C, R30.2
RB6: U$8.26 (PGEC1/AN6/OCFA/RB6), X1.5
RB7: U$8.27 (PGED1/AN7/RB7), X1.4
RE2: R20.2, U$8.98 (AN26/RE2)
RELAY: JP5.2, U$8.39 (*U2RTS/RF13)
RIGHT_BT: U$1.39 (SPKR_R+), U$15.10 (S2B)
RIGHT_CODEC: U2.39 (RIGHT), U$15.8 (S1B)
SDCD: R9.1, U1.CD, U$8.7 (AN17/T3CK/T6CK/RC2)
SDCLK: U1.5 (CLK), U$8.10 (SCK2/CN8/RG6)
SDCS: R7.1, U1.1 (CD/DAT3), U$8.6 (AN16/T2CK/T7CK/RC1)
SDI: R8.1, U1.2 (CMD), U$8.12 (SDO2/CN10/RG8)
SDO: R6.1, U1.7 (DAT0), U$8.11 (SDI2/CN9/RG7)
SDWP: R10.1, U1.WP, U$8.8 (AN18/T4CK/T9CK/RC3)
TO_RX: U$1.16 (UART_RX), U$8.51 (U1TX/RF3)
TO_TX: U$1.15 (UART_TX), U$8.52 (U1RX/RF2)
VCC: C1.1, C8.1, C9.1, C11.1, C15.1, C16.+, C18.+, C19.1, C20.1, C25.1, C32.1, IC2.3 (VO), JP3.8, JP4.8, R2.2, R6.2, R7.2, R8.2, R9.2, R10.2, R18.2, R19.1, U1.4 (VDD), U2.6 (IOVDD), U2.14 (IOVDD), U2.19 (IOVDD), U2.26 (RX), U2.32 (XTEST), U2.38 (AVDD), U2.43 (AVDD), U2.45 (AVDD), U$1.17 (GPIO7), U$1.19 (PWREN), U$1.20 (VDD), U$8.2 (VDD_2), U$8.16 (VDD_3), U$8.29 (VREF+/RA10), U$8.30 (AVDD), U$8.37 (VDD_4), U$8.46 (VDD_5), U$8.62 (VDD_6), U$8.85 (VCAP/VDDCORE), U$8.86 (VDD), X1.2
VDD: C7.1, C21.1, C30.1, C31.1, DC1.1 (VIN), IC1.3 (VO), IC2.1 (VI), IC3.8 (V+), LED3.A, R14.2, R15.2, S2.+ (A), U$2.3 (VCC), U$15.1 (1-VDD)
VFDBLANK: JP3.4, U$8.57 (SCL1/RG2)
VFDCLOCK: JP3.2, U$8.38 (TCK/RA1)
VFDDATA: JP3.1, U$8.58 (SCL2/RA2)
VFDLATCH: JP3.3, U$8.49 (U2RX/CN17/RF4)
VPP: D2.A, S3.1A (1), S3.1B (1)

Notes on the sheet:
0.1u
3.3V
470u
0.47u
33u

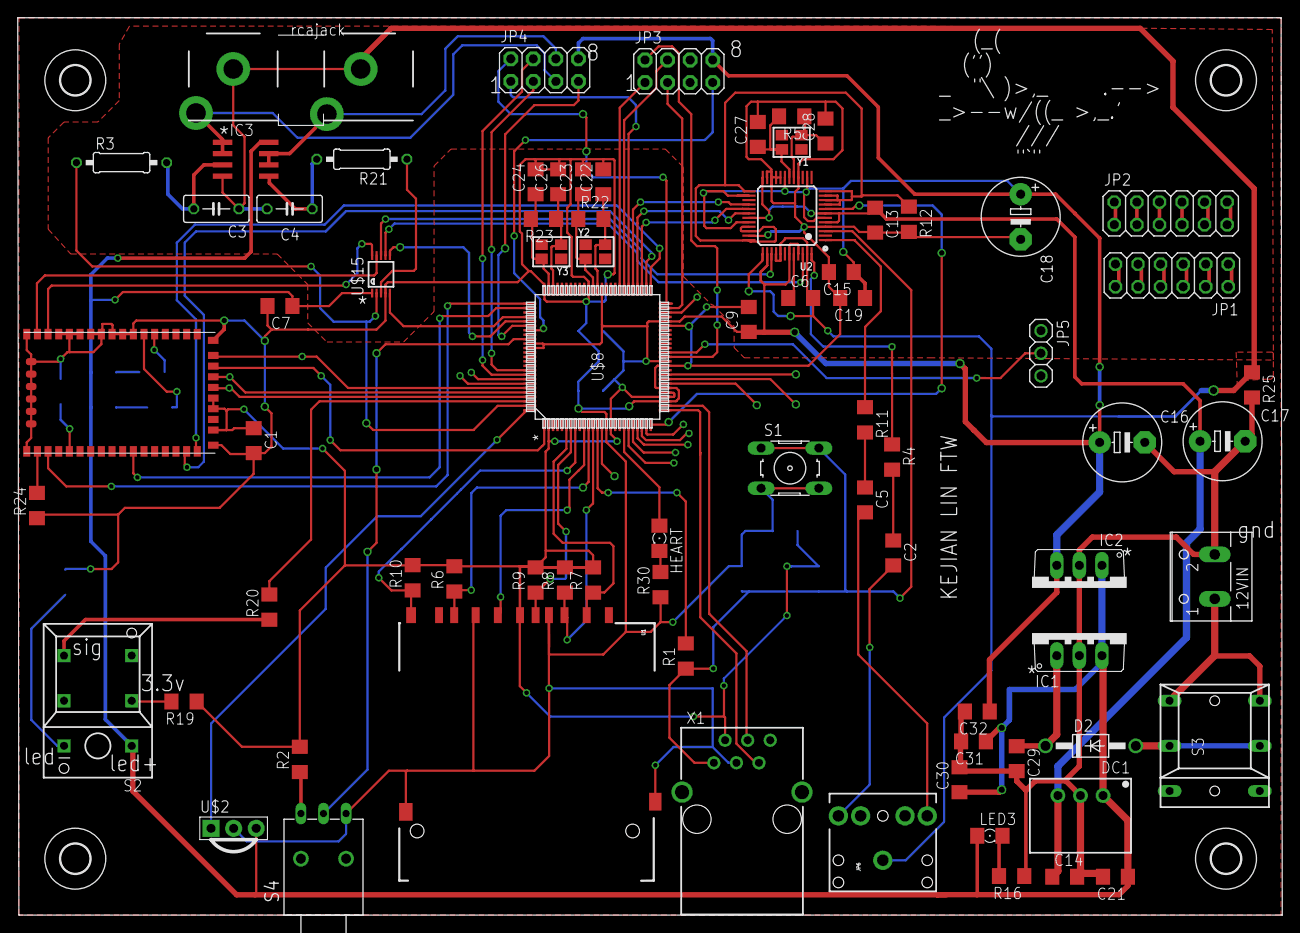
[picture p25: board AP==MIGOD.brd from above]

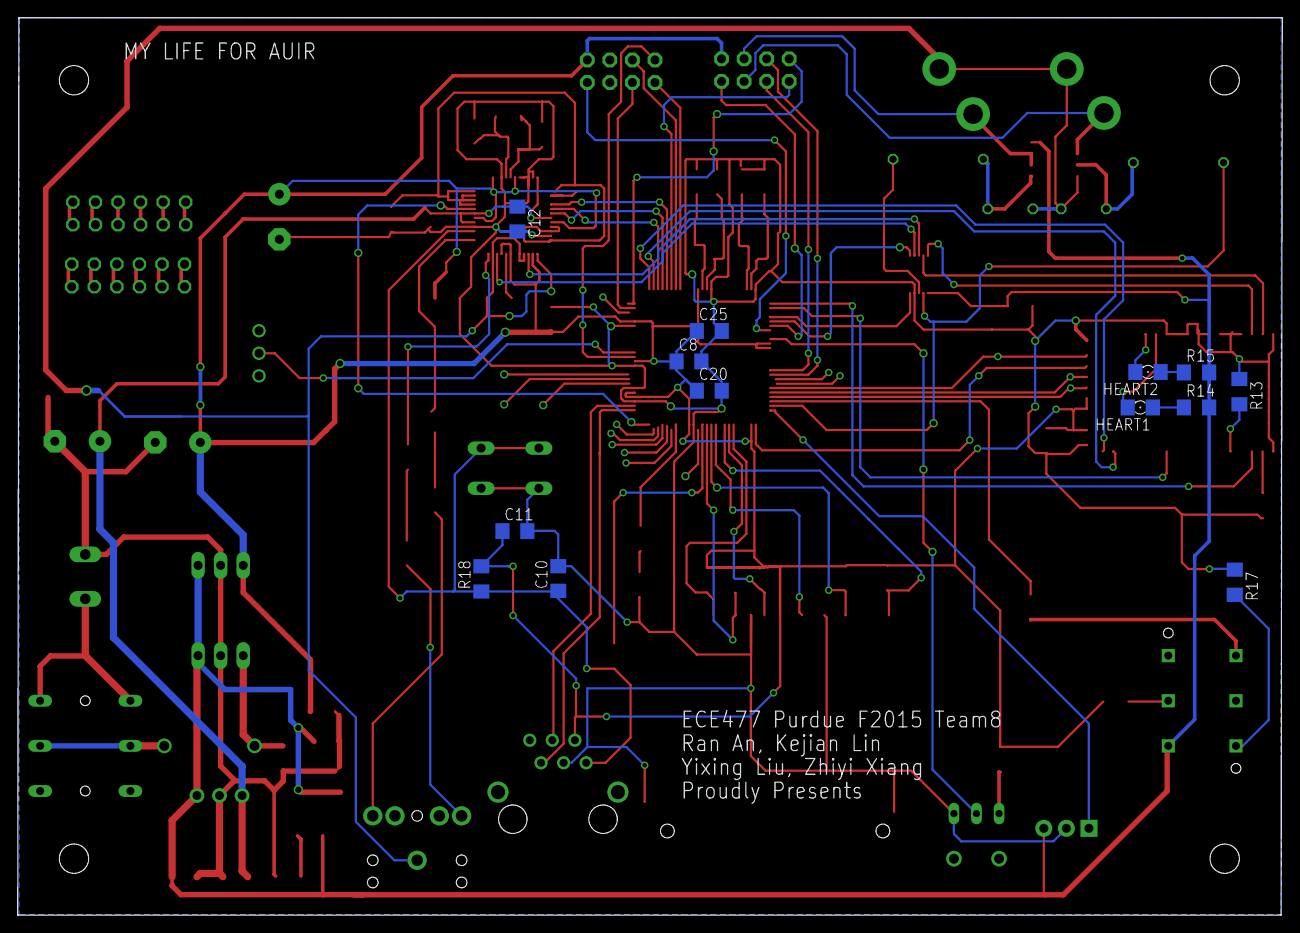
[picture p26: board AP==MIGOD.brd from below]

Board: 2 copper layers, 142.3 x 101.0 mm, 93 parts (13 on the bottom side), 83 nets.

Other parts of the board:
U$9, U$10, U$11, U$12: 3,3

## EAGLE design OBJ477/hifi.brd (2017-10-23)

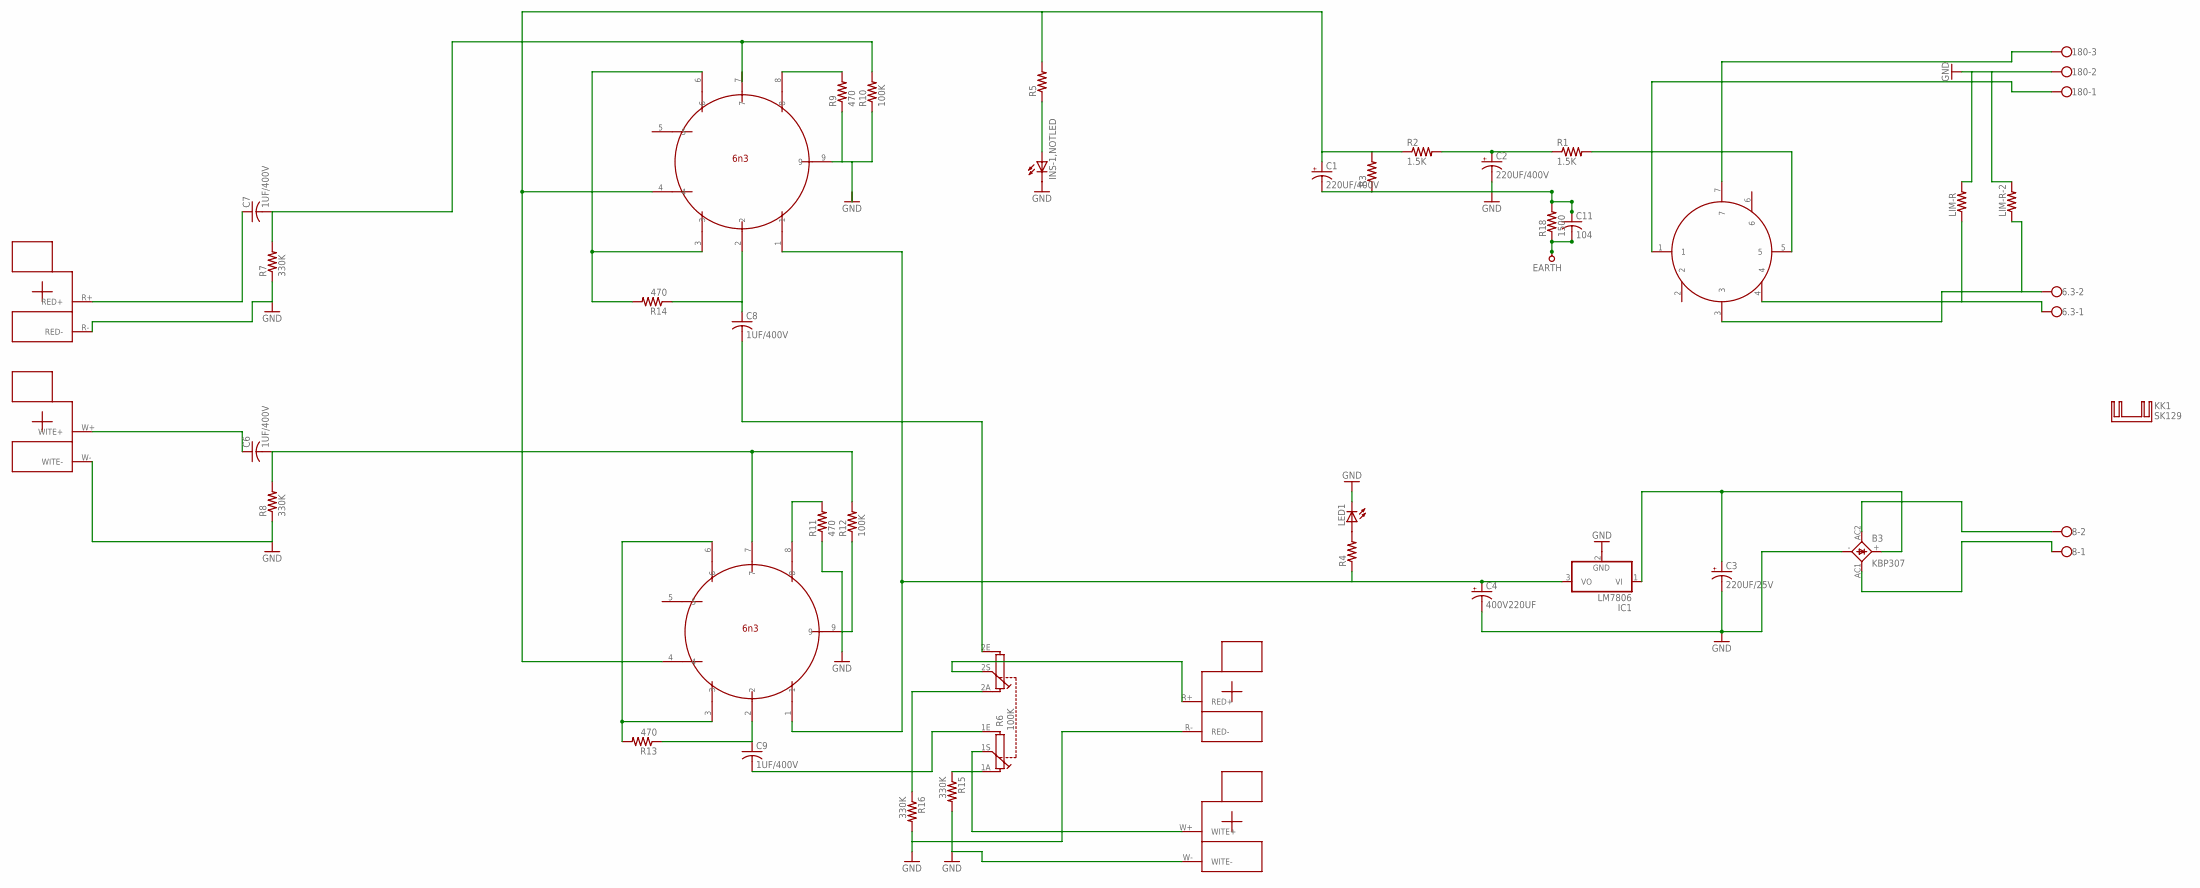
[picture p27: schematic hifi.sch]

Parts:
6.3, 8: W237-102
180: W237-103
B3: KBP307; KBL
C1, C2: 220UF/400V; EB35D
C3: 220UF/25V; E3,5-10
C4: 400V220UF; EB30D
C6, C7, C8, C9: 1UF/400V; C375-192X418
C11: 104; C075-052X106
EARTH: PAD_TERMINAL-4.1MMROUND; PAD_ROUND_4.1MM
IC1: LM7806; TO220V
INS-1,NOTLED: LED5MM
KK1: SK129; SK129-HOLE
LED1: LED5MM
LIM-R: R-US_0207/10; 0207/10
LIM-R-2: R-US_0207/10; 0207/10
R1, R2: 1.5K; 0309/12
R3, R5: R-US_0309/12; 0309/12
R4: R-US_0207/10; 0207/10
R6: 100K; PC16D
R7, R8, R15, R16: 330K; 0207/10
R9, R11, R13, R14: 470; 0207/10
R10, R12: 100K; 0207/10
R18: 1500; 0309/12
U$1: 6Z4-SIMPLE; MINI_P7
U$2, U$3: 6N3-SIMPLE; NOVAL
U$4, U$5: RCANEW; RCA

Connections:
GND: 180.2, B3.-, C1.-, C2.-, C3.-, C4.-, C11.1, IC1.2 (GND), INS-1,NOTLED.K (C), LED1.K (C), LIM-R.2, LIM-R-2.2, R3.1, R7.1, R8.1, R11.1, R12.1, R15.2, R16.2, R18.2, U$3.9, U$4.R- (RED-), U$4.W- (WITE-), U$5.R- (RED-), U$5.W- (WITE-)
unnamed: 180.3, U$1.7
unnamed: 8.2, B3.AC2 (AC1)
unnamed: 180.1, U$1.1
unnamed: 6.3.1, LIM-R.1, U$1.4
unnamed: 6.3.2, LIM-R-2.1, U$1.3
unnamed: 8.1, B3.AC1 (AC2)
unnamed: B3.+, C3.+, IC1.1 (VI)
unnamed: C4.+, IC1.3 (VO), R4.1, U$2.1, U$3.1
unnamed: INS-1,NOTLED.A, R5.1
unnamed: C2.+, R1.1, R2.2
unnamed: C11.2, EARTH.P, R18.1
unnamed: C6.1, U$4.W+ (WITE+)
unnamed: R1.2, U$1.5
unnamed: C1.+, R2.1, R3.2, R5.2, U$2.4, U$3.4
unnamed: C7.1, U$4.R+ (RED+)
unnamed: LED1.A, R4.2
unnamed: R6.1S, U$5.W+ (WITE+)
unnamed: C8.1, R14.1, U$2.2
unnamed: C7.2, R7.2, R10.2
unnamed: C6.2, R8.2, R12.2, U$3.7
unnamed: R14.2, U$2.3, U$2.6
unnamed: C8.2, R6.2E
unnamed: R6.2A, R16.1
unnamed: R6.1A, R15.1
unnamed: C9.2, R6.1E
unnamed: C9.1, R13.1, U$3.2
unnamed: R13.2, U$3.3, U$3.6
unnamed: R6.2S, U$5.R+ (RED+)
unnamed: R9.1, R10.1, U$2.9
unnamed: R9.2, U$2.8
unnamed: R11.2, U$3.8

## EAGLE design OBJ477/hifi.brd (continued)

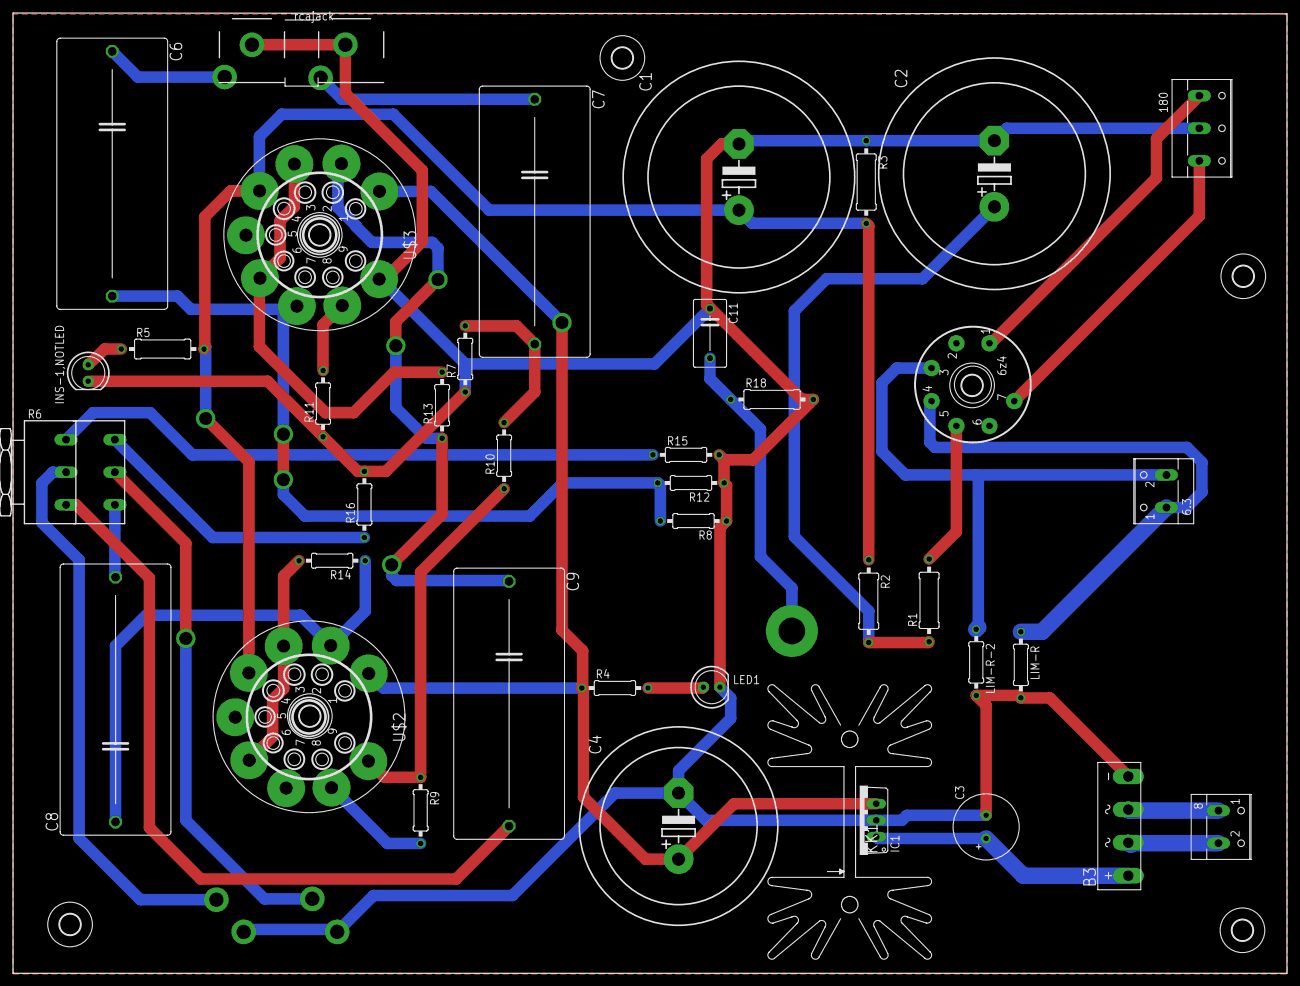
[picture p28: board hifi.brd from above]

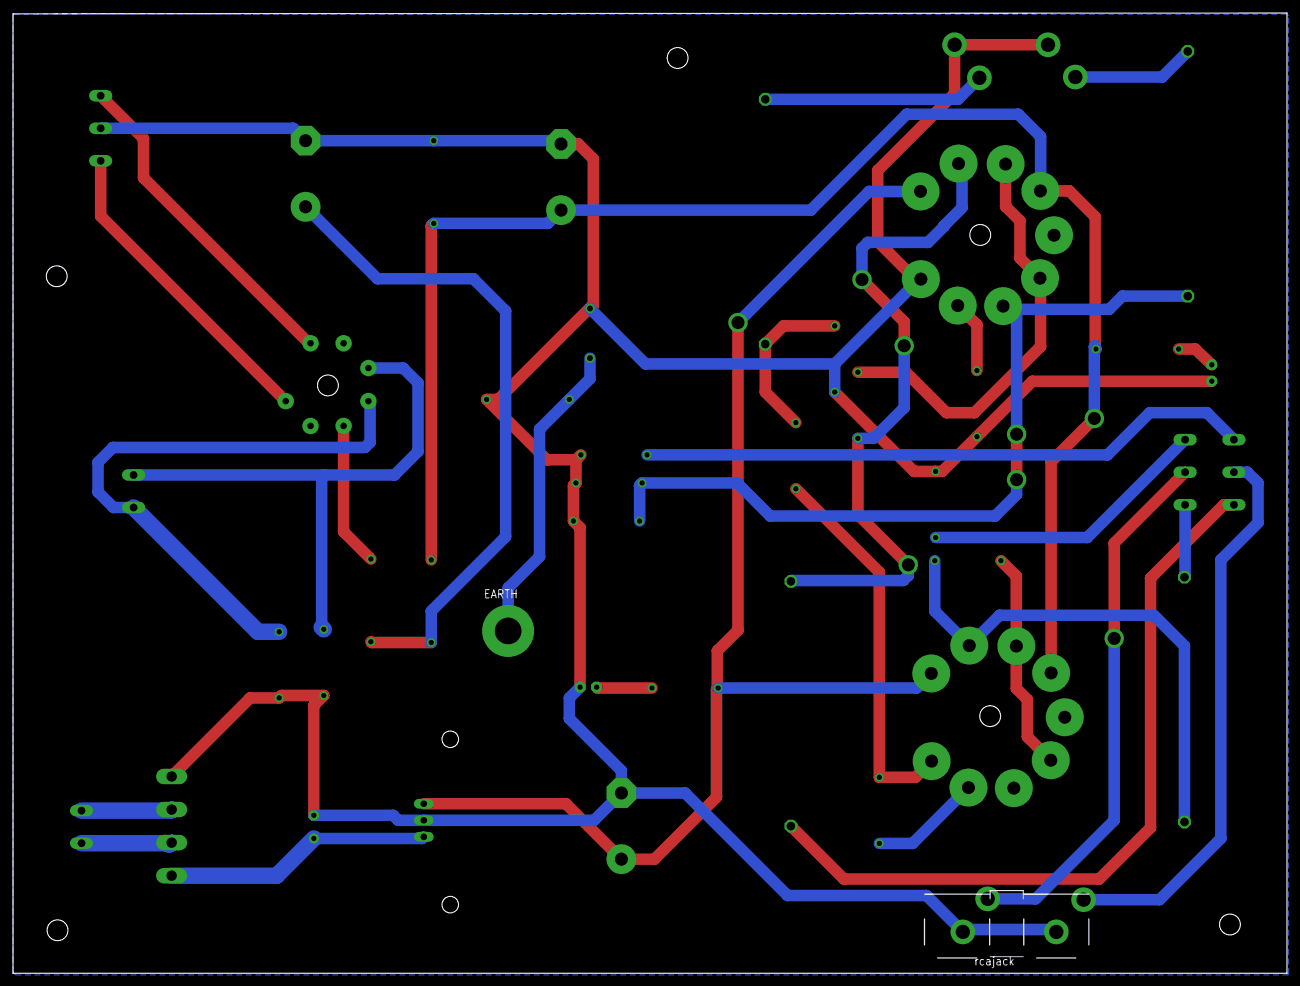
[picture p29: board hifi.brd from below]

Board: 2 copper layers, 195.7 x 147.5 mm, 49 parts (2 on the bottom side), 32 nets.

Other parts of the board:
U$6, U$7, U$8, U$9, U$10, U$11, U$12: 3,2

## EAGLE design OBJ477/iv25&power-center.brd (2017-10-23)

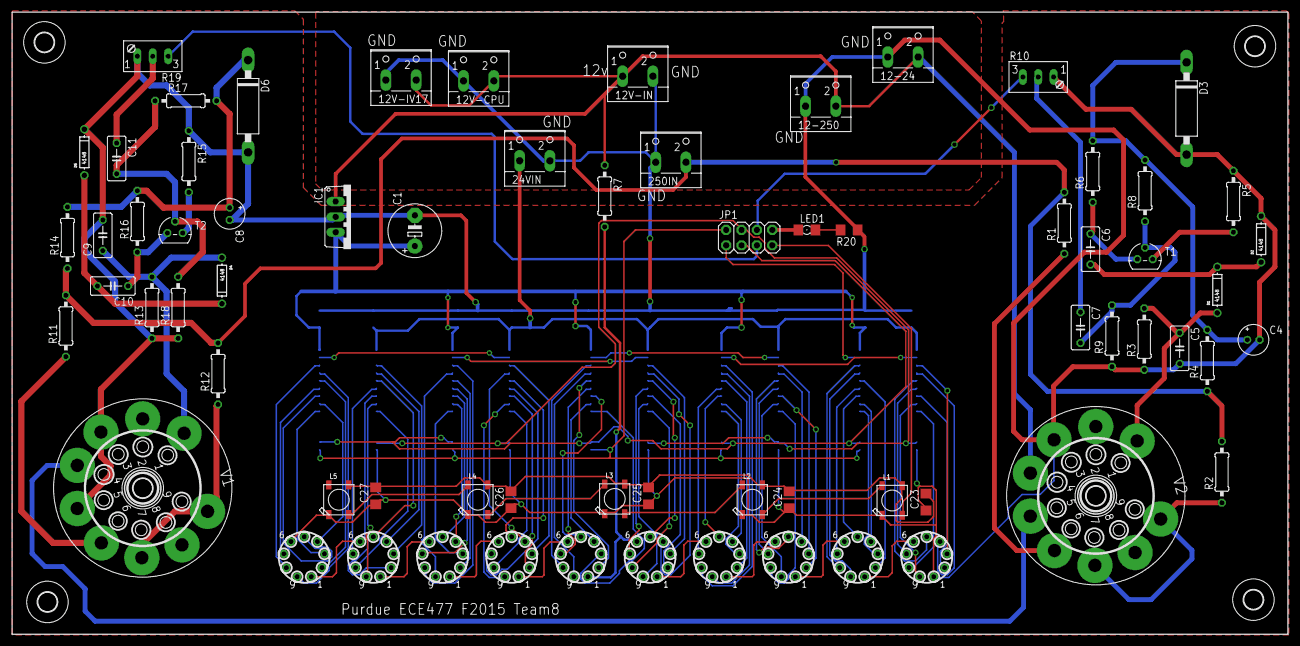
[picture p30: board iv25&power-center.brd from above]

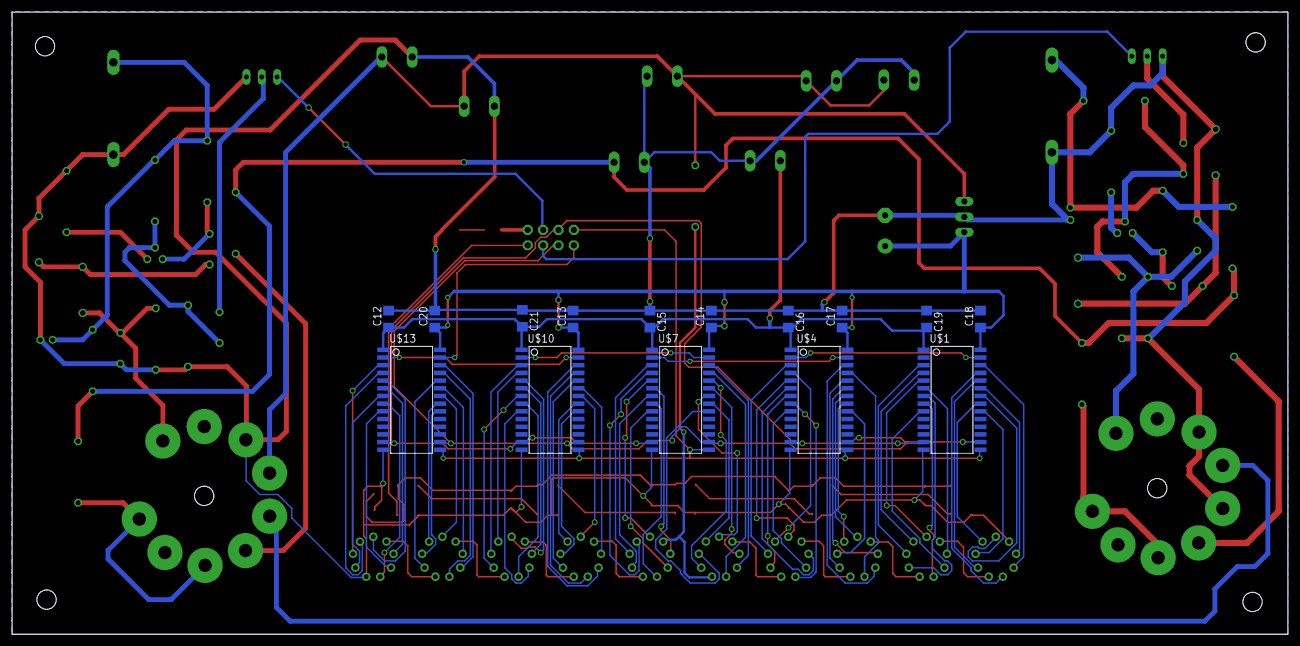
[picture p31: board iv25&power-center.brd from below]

Board: 2 copper layers, 210.8 x 102.8 mm, 90 parts (15 on the bottom side), 121 nets.

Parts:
12-24, 12-250, 12V-CPU, 12V-IN, 12V-IV17, 24VIN, 250IN: W237-102
C1: E5-8,5
C4, C8: 10uf/35v; E2-5
C5, C6, C7, C9, C10, C11: 100NF; C050-030X075
C12, C13, C14, C15, C16, C17, C18, C19, C20, C21: 100nf; C1206
C23, C24, C25, C26, C27: C1206
D1, D2, D4, D5: 4148; DO-1N4148
D3, D6: Z-30V; C1702-15
IC1: 7805TV; TO220V
JP1: 2X04
L1, L2, L3, L4, L5: WS2812B
LED1: 1206
R1, R11: 10k; 0207/10
R2, R12: 470k; 0207/10
R3, R8, R13, R17: 1M; 0207/10
R4, R14: 100k/1w; 0207/10
R5, R15: 2.7K; 0207/10
R6, R16: 47K; 0207/10
R7: 20ohm; 0207/10
R9, R18: 56K; 0207/10
R10, R19: 100K; S64W
R20: R1206
T1, T2: BC546; TO92
U$1, U$4, U$7, U$10, U$13: MAX6921; SOIC-28W
U$2, U$3, U$5, U$6, U$8, U$9, U$11, U$12, U$14, U$15: IV25; NIXIE-9
U$16, U$17, U$18, U$19, U$20, U$21: 3,2
V1, V2: NOVAL

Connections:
5VDC: C1.+, C13.1, C14.1, C17.1, C18.1, C20.1, IC1.3, U$1.28, U$4.28, U$7.28, U$10.28, U$13.28
12VDC: 12-24.2, 12-250.2, 12V-CPU.2, 12V-IN.1, 12V-IV17.2, IC1.1, R7.1, V2.4
24VDC: 24VIN.1, C12.1, C15.2, C16.2, C19.2, C21.2, U$1.1, U$4.1, U$7.1, U$10.1, U$13.1
+5V: C23.2, C24.2, C25.2, C26.2, C27.2, L1.1-VDD, L2.1-VDD, L3.1-VDD, L4.1-VDD, L5.1-VDD
AGND: 12-24.1, 12-250.1, 12V-CPU.1, 12V-IN.2, 12V-IV17.1, 24VIN.2, 250IN.1, C1.-, C4.-, C5.2, C8.-, C9.2, C12.2, C13.2, C14.2, C15.1, C16.1, C17.2, C18.2, C19.1, C20.2, C21.1, C23.1, C24.1, C25.1, C26.1, C27.1, D2.C, D3.A, D5.C, D6.A, IC1.2, L1.3-GND, L2.3-GND, L3.3-GND, L4.3-GND, L5.3-GND, R3.1, R5.1, R9.1, R10.A, R13.1, R15.1, R18.1, R19.A, R20.1, U$1.14, U$2.6, U$4.14, U$7.14, U$10.14, U$13.14, U$15.1, V1.3, V1.5, V2.3
AUDIO-L: JP1.5, R19.E
AUDIO-R: JP1.6, R10.E
BLANK: JP1.4, U$1.13, U$4.13, U$7.13, U$10.13, U$13.13
CLOCK: JP1.2, U$1.15, U$4.15, U$7.15, U$10.15, U$13.15
DATA: JP1.1, U$13.27
LED-DATA: JP1.7, L1.4-DIN
LOAD: JP1.3, U$1.16, U$4.16, U$7.16, U$10.16, U$13.16
unnamed: U$1.24, U$2.2
unnamed: U$1.20, U$2.3
unnamed: U$1.21, U$2.4
unnamed: U$1.22, U$2.5
unnamed: U$1.23, U$2.7
unnamed: U$1.26, U$2.8
unnamed: U$1.25, U$2.9
unnamed: U$1.7, U$3.2
unnamed: U$1.3, U$3.3
unnamed: U$1.4, U$3.4
unnamed: U$1.5, U$3.5
unnamed: U$1.6, U$3.7
unnamed: U$1.9, U$3.8
unnamed: U$1.8, U$3.9
unnamed: L1.2-DOUT, L2.4-DIN
unnamed: U$4.24, U$5.2
unnamed: LED1.C, R20.2
unnamed: U$4.20, U$5.3
unnamed: U$4.21, U$5.4
unnamed: U$4.22, U$5.5
unnamed: U$4.23, U$5.7
unnamed: U$4.26, U$5.8
unnamed: U$4.25, U$5.9
unnamed: U$4.7, U$6.2
unnamed: U$4.3, U$6.3
unnamed: U$4.4, U$6.4
unnamed: U$4.5, U$6.5
unnamed: U$4.6, U$6.7
unnamed: U$4.9, U$6.8
unnamed: U$4.8, U$6.9
unnamed: U$7.24, U$8.2
unnamed: U$7.20, U$8.3
unnamed: L2.2-DOUT, L3.4-DIN
unnamed: U$7.21, U$8.4
unnamed: U$7.22, U$8.5
unnamed: U$1.27, U$4.2
unnamed: U$7.23, U$8.7
unnamed: U$7.26, U$8.8
unnamed: U$7.25, U$8.9
unnamed: U$7.7, U$9.2
unnamed: U$7.3, U$9.3
unnamed: U$7.4, U$9.4
unnamed: U$7.5, U$9.5
unnamed: U$7.6, U$9.7
unnamed: U$7.9, U$9.8
unnamed: U$7.8, U$9.9
unnamed: U$10.24, U$11.2
unnamed: U$10.20, U$11.3
unnamed: U$10.21, U$11.4
unnamed: U$10.22, U$11.5
unnamed: L3.2-DOUT, L4.4-DIN
unnamed: U$10.23, U$11.7
unnamed: U$10.26, U$11.8
unnamed: U$4.27, U$7.2
unnamed: U$10.25, U$11.9
unnamed: U$10.7, U$12.2
unnamed: U$10.3, U$12.3
unnamed: U$10.4, U$12.4
unnamed: U$10.5, U$12.5
unnamed: U$10.6, U$12.7
unnamed: U$10.9, U$12.8
unnamed: U$10.8, U$12.9
unnamed: U$13.24, U$14.2
unnamed: U$13.20, U$14.3
unnamed: U$13.21, U$14.4
unnamed: U$13.22, U$14.5
unnamed: U$13.23, U$14.7
unnamed: U$13.26, U$14.8
unnamed: L4.2-DOUT, L5.4-DIN
unnamed: U$13.25, U$14.9
unnamed: U$13.7, U$15.2
unnamed: U$13.3, U$15.3
unnamed: U$13.4, U$15.4
unnamed: U$13.5, U$15.5
unnamed: U$13.6, U$15.7
unnamed: U$13.9, U$15.8
unnamed: U$13.8, U$15.9
unnamed: U$2.1, U$3.6
unnamed: U$3.1, U$5.6
unnamed: U$5.1, U$6.6
unnamed: U$6.1, U$8.6
unnamed: U$14.1, U$15.6
unnamed: U$12.1, U$14.6
unnamed: U$11.1, U$12.6
unnamed: U$9.1, U$11.6
unnamed: R7.2, U$8.1, U$9.6
unnamed: C10.2, D4.C, D5.A
unnamed: C6.2, D1.C, D2.A
unnamed: C6.1, R6.1, T1.3
unnamed: V1.4, V2.5
unnamed: R2.1, V2.7, V2.9
unnamed: R1.1, V2.6
unnamed: C5.1, D1.A, R3.2, V2.1
unnamed: C4.+, D3.C, R4.2, R6.2, R8.2
unnamed: R5.2, T1.1
unnamed: 250IN.2, R1.2, R2.2, R4.1, R11.2, R12.2, R14.1
unnamed: R12.1, V1.7, V1.9
unnamed: R11.1, V1.6
unnamed: C7.2, R8.1, R9.2, T1.2
unnamed: C9.1, D4.A, R13.2, V1.1
unnamed: C7.1, R10.S
unnamed: C8.+, D6.C, R14.2, R16.2, R17.2
unnamed: C10.1, R16.1, T2.3
unnamed: R15.2, T2.1
unnamed: C11.2, R17.1, R18.2, T2.2
unnamed: C11.1, R19.S
unnamed: U$10.27, U$13.2
unnamed: U$7.27, U$10.2
unnamed: JP1.8, LED1.A

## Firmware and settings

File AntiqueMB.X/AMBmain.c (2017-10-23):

/* 
 * File:   AMBmain.c
 * Author: Yixing Liu, Zhiyi Xiang, Ran An, Kejian Lin
 * Description: This code is for the Antique Music Box that utilize Reading SD 
 * card through SPI module and connect with Smartphone in Bluetooth through UART
 * module
 *
 * Created on November 22, 2015, 3:52 PM
 */

#include "p33fxxxx.h"


#include <stdio.h>
#include <stdlib.h>
#include <stddef.h>
#include <stdbool.h>
#include <xc.h>
#include <math.h>
#include <dsp.h>

#include "configuration_pins.h"
#include "VFDdisplayMessage.h"
#include "VFDbar.h"
#include "SD-SPI.h"
#include "FSIO.h"
#include "vs1053.h"
#include "ADC.h"

// External Oscillator

_FOSCSEL(FNOSC_FRC);		
_FOSC(FCKSM_CSECMD & OSCIOFNC_OFF  & POSCMD_HS);  
								// Clock Switching is enabled and Fail Safe Clock Monitor is disabled
								// OSC2 Pin Function: OSC2 is Clock Output
								// Primary Oscillator Mode: XT Crystal


_FWDT(FWDTEN_OFF);              // Watchdog Timer Enabled/disabled by user software
								// (LPRC can be disabled by clearing SWDTEN bit in RCON register
#define True 1
#define False 0

#define MAXBUFFERSIZE 32

#define  SAMP_BUFF_SIZE	 		64		// Size of the input buffer per analog input
#define SAMPLING_RATE		8000   /* = Rate at which input signal was sampled */
#define  MAX_CHNUM	 			10		// Highest Analog input number enabled for alternate sampling
#define  log2N    6
#define  fftPoints	(1<<log2N)

int  BufferA[MAX_CHNUM+1][SAMP_BUFF_SIZE] __attribute__((space(dma),aligned(64)));
//int  BufferB[MAX_CHNUM+1][SAMP_BUFF_SIZE] __attribute__((space(dma),aligned(64)));
int  BufferB[64];

SearchRec file;
unsigned char attributes = ATTR_HIDDEN | ATTR_SYSTEM | ATTR_READ_ONLY | ATTR_VOLUME| ATTR_ARCHIVE;
char extention[] = "*.mp3";
int findfile = 0;   
FSFILE * pointer; 
unsigned char section[MAXBUFFERSIZE];
unsigned int timer_counter = 0;
const fractcomplex twiddleFactors[] __attribute__ ((space(auto_psv), aligned (fftPoints * 2))) = {
	0x7FFF, 0x0000, 0x7F62, 0xF374, 0x7D8A, 0xE707, 0x7A7D, 0xDAD8,
	0x7642, 0xCF04, 0x70E3, 0xC3A9, 0x6A6E, 0xB8E3, 0x62F2, 0xAECC,
	0x5A82, 0xA57E, 0x5134, 0x9D0E, 0x471D, 0x9592, 0x3C57, 0x8F1D,
	0x30FC, 0x89BE, 0x2528, 0x8583, 0x18F9, 0x8276, 0x0C8C, 0x809E,
	0x0000, 0x8000, 0xF374, 0x809E, 0xE707, 0x8276, 0xDAD8, 0x8583,
	0xCF04, 0x89BE, 0xC3A9, 0x8F1D, 0xB8E3, 0x9592, 0xAECC, 0x9D0E,
	0xA57D, 0xA57D, 0x9D0E, 0xAECC, 0x9592, 0xB8E3, 0x8F1D, 0xC3A9,
	0x89BE, 0xCF04, 0x8583, 0xDAD8, 0x8276, 0xE707, 0x809E, 0xF374
};


#define FILTER_LEN  10
double FirCoeff[ FILTER_LEN ] ={-1468, 1058,   594,   287,    186,  284,   485,   613, 495,   90  };


int index = 50000;
int DMA_counter = 0;

fractional	inputData[fftPoints];
// Initial FFTdata
fractcomplex fftData[fftPoints] __attribute__ ((section (".ybss, bss, ymemory"), aligned (fftPoints * 2 * 2)));
fractional	powerSpec[fftPoints/2];

unsigned short int currentVolume, scibass=0, memtest=0, clock=0, scimode=0, scistatus=0, hdat0=0, hdat1=0, samplerate=0;

void InitClock(void);
void InitSPI(void);
void Init_Timer1( void );
void Init_Timer2 (void);
void InitUART1(void);
void ws2812_send(ws2812_ptr);

void initAdc1(void);
void initTmr3();
void initDma0(void);
void __attribute__((__interrupt__)) _DMA0Interrupt(void);
void ProcessADCSamples(int * AdcBuffer);
void FFT(int * inputData);
void RunFIRFilter(double *FirCoeff, int NumTaps, double *Signal, int NumSigPts);
 int timer1_counter = 0;
 int timer2_counter = 0;

 int tick = 0;
 int second=0;
 int minute=0;
 int hour=0;
int song_is_over = 0;
int SD = 0;
int BT = 0;
int RECEIVE;
int play = 0;
int stop = 0;
int next = 0;
int first = 0;
int next_timer = 0;
int led_i = 0;

//int index = 50000;
char str[4] = {0};
long data[10] = {1,2,3,4,5,6,7,7,6,5};


unsigned long int bitflip(unsigned char b);
typedef struct {
    unsigned char   r;
    unsigned char   b;
    unsigned char   g;
} ws2812_ptr;
ws2812_ptr led;

#define FCY 9000000
#define BAUDRATE 115200
#define BRGVAL FCY/BAUDRATE/4 - 1

void __attribute__((__interrupt__, no_auto_psv)) _T1Interrupt(void)
{
    /* Interrupt Service Routine code goes here */
    IFS0bits.T1IF = 0;  //Clear Timer1 interrupt flag
    T1CONbits.TON = 0;  // disable timer

    timer1_counter ++;
    if(timer1_counter == 1000)
    {
        LATAbits.LATA13 = !LATAbits.LATA13;
        second = second + 1;
        if(second == 60)
        {
            minute = minute + 1;
            second = 0;
        }
        if(minute == 60)
        {
            hour = hour + 1;
            minute = 0;
        }
        if(hour == 12 && minute==60)
        {
            hour = 0;
            minute = 0;
            second = 0;
        }
        timer1_counter = 0;
    }
    

    
    TMR1 = 0;   
    T1CONbits.TON = 1;
}
    

void __attribute__((__interrupt__, no_auto_psv)) _T2Interrupt(void)
{
/* Interrupt Service Routine code goes here */
    IFS0bits.T2IF = 0;     //Clear Timer1 interrupt flag
    T2CONbits.TON = 0;  // disable timer

    if(play == 1)
    {
        if(index < 25000)
            VFDbar(data,1);
        else
            VFDbar(data,1);
        index--;
        if(index == 0)
            index = 50000;
    }
    
    if(play == 0)
    {
//            if(index < 25000)
//            VFDbar(data,0);
//        else
//            VFDbar(data,0);
//        index--;
//        if(index == 0)
//            index = 50000;
    }
    TMR2 = 0;   
    T2CONbits.TON = 1;
    
//    if(next == 1)
//    {
//        if(index < 25000)
//            VFDbar(data);
//        else
//            VFDbar(data);
//        index--;
//        if(index == 0)
//            index = 50000;
//    }
    
//    if(led_i <= 3)
//    {
//        LED_VFD = 1;
//        LED_BAR = 1;
//        led_i++;
//    }
//    else
//    {
//        LED_VFD = 0;
//        LED_BAR = 1;
//        led_i++;
//    }
//    if(led_i == 10)
//        led_i = 0;
}

void __attribute__((__interrupt__, no_auto_psv)) _T3Interrupt(void)
{
/* Interrupt Service Routine code goes here */
    IFS0bits.T3IF = 0;     //Clear Timer3 interrupt flag
    T3CONbits.TON = 0;  // disable timer

    TMR3 = 0;   
    T3CONbits.TON = 1;
}

void __attribute__ ((interrupt, no_auto_psv)) _U1RXInterrupt(void)
{
    if(U1STAbits.OERR == 1)
    {
        U1STAbits.OERR = 0;
    }
    RECEIVE = U1RXREG;

    {
        if(RECEIVE == 'c')
        {
            if(play == 0)
            {
                play = 1;
            }
            else
            {
                play = 0;
            }
        }

        if(RECEIVE == 'd')
        {
            next = 1;
        
        }

        if( RECEIVE == 'a')
        {
            SD = 1;
            BT = 0;
            mux1 = 0;
            mux2 = 0;   // mux1 = mux2 = 0 = SD card

        }
        if( RECEIVE == '5')
        {
           BT = 1; 
           SD = 0;
           play = 0;
           next = 0;
           mux1 = 1;
           mux2 = 1;   // mux1 = mux2 = 1 = BT
           VFDdisplayMessage(" Morning  ");
        }
        if( RECEIVE == '6')
        {
           BT = 1; 
           SD = 0;
           play = 0;
           next = 0;
           mux1 = 1;
           mux2 = 1;   // mux1 = mux2 = 1 = BT
           VFDdisplayMessage("Afternoon ");
        }
        
        if( RECEIVE == '7')
        {
           BT = 1; 
           SD = 0;
           play = 0;
           next = 0;
           mux1 = 1;
           mux2 = 1;   // mux1 = mux2 = 1 = BT
           VFDdisplayMessage("Evening");
        }
        
    }
    IFS0bits.U1RXIF = 0;
}
//


unsigned int DmaBuffer = 0;
void __attribute__((interrupt, no_auto_psv)) _DMA0Interrupt(void)
{	
    
    RunFIRFilter( &FirCoeff, 10, &BufferA[10][0], 10);

  
  //  if(play == 1)
    //    ProcessADCSamples(&BufferA[10][0]); 
//    int i;	 
//    for(i=0;i<16;i++)
//    {
//        BufferB[j] = BufferA[10][i];
//        j++;
//    }
//	if( DMA_counter == 3)
//    {
//        ProcessADCSamples(&BufferB);
//        DMA_counter = 0;
//        j = 0;
//    }
//    DMA_counter ++;
    
    IFS0bits.DMA0IF = 0;		//Clear the DMA0 Interrupt Flag
}

int main(void)
{    
    
    Configure_Pins();  
    //InitClock();
    
//    VFDdisplayMessage("HelloWorld");
    
//    while(1) {
//        // timing on the WS2812B is very precise. turn off interrupts before talking
//        //GIE = 0; while (GIE);
//        ws2812_send(&led);
//        //GIE = 1; while (!GIE);
//        led.b = 0;
//        delay(10);
//        ws2812_send(&led);
//        delay(10);
//        led.b = 120;
//    }
        

    VFDdisplayMessage("Welcome  ");
    delay(200);
    
    InitClock();
    
    Init_Timer1();
  //  Init_Timer2();
    
    // Peripheral Initialisation
  	//initAdc1();             	// Initialize the A/D converter to convert Channel 5
	//initDma0();					// Initialise the DMA controller to buffer ADC data in conversion order
    //while(1);
    
    InitSPI(); 
    vs1053Config();										// Open SPI2 and Set Pin
    vs1053Reset();										// Reset MP3 Player
    vs1053Init();										// initializes the vs1053 mp3 player to "New" modes
    scimode = vs1053SCIRead(SCI_MODE);
    scistatus = vs1053SCIRead(SCI_STATUS);	
    vs1053SCIWrite(SCI_BASS, 0x44);
    scibass = vs1053SCIRead(SCI_BASS);
    clock = vs1053SCIRead(SCI_CLOCKF);
    vs1053SCIWrite(SCI_AUDATA, 0xAC45);
    samplerate = vs1053SCIRead(SCI_AUDATA);

    while(!MDD_MediaDetect())
    {
        VFDdisplayMessage("No media  ");
    }

    FSInit();
    findfile = FindFirst(extention,attributes,&file);
    if ( findfile == 0)
    {
        first = 1;
        pointer = FSfopen(file.filename,"r");  // open current file
    }

    delay(100);
    

    
        
    // test adc
    led.r = 120;
    led.g = 120;
    led.b = 120;
    
 // Peripheral Initialisation

    
    // Initialise the Timer to generate sampling event to ADC @ 8Khz rate
    VFDdisplayMessage("Play Song ");
    
    InitUART1();
        
 //   initAdc1();             	// Initialize the A/D converter to convert Channel 5
//	initDma0();					// Initialise the DMA controller to buffer ADC data in conversion order
//	initTmr3();		
    
    while(1)
    {
        if(play == 1)
        {
            if(first == 1)
            {
                VFDdisplayMessage(file.filename);
                first = 0;
            }
            while(1)
            {
                if(next == 1 || song_is_over == 1)
                {
                    findfile = FindNext(&file);
                    if(findfile != 0)
                    {
                        findfile = FindFirst(extention,attributes,&file);
                    }
                }
                if(findfile == 0)   // file find success
                {
                    if(song_is_over == 1||next == 1)
                    {
                        VFDdisplayMessage(file.filename);
                        pointer = FSfopen(file.filename,"r");  // open current file
                        next = 0;
                        song_is_over = 0;
                    }
                    if(pointer == NULL)
                        while(1);
                    while(FSfeof(pointer) == 0)
                    {
                        FSfread(section,1,MAXBUFFERSIZE,pointer);
                        while(X_DREQ != 1);
                        vs1053SendMusic(section,MAXBUFFERSIZE);
                        if(play == 0 || next == 1)
                            break;
                    }
                    if(FSfeof(pointer) != 0)
                    {    
                        song_is_over = 1;
                    }
                    FSfclose(pointer);
                    SendZerosToVS1053();
                }
                else
                    VFDdisplayMessage("Insert SD");
                if( play == 0 )
                    break;
            }
        }
        if(play == 0)
        {
         
//            
//                char time[10]={0};
//                time[0] = hour;
//                time[1] = minute;
//                time[2] =':';
//                time[3] = second;
//                time[4] = '\0';    
//                VFDdisplayMessage(time);
            if(play == 1)
                break;
            
            next = 0;
          //  VFDdisplayMessage("Bluetooth");
        }
    }
}

void RunFIRFilter(double *FirCoeff, int NumTaps, double *Signal,int NumSigPts)
{
  int j, k, n, Top = 0;
  double y, Reg[NumTaps];  // This assumes <= 256 taps.
  int FilteredSignal[10] = {0};
  
  for(j=0; j<NumTaps; j++)Reg[j] = 0.0;

  for(j=0; j<NumSigPts; j++)
   {
    Reg[Top] = Signal[j];
    y = 0.0;
    n = 0;

    // The FirCoeff index increases while the Reg index decreases.
    for(k=Top; k>=0; k--)
     {
      y += FirCoeff[n++] * Reg[k];
     }
    for(k=NumTaps-1; k>Top; k--)
     {
      y += FirCoeff[n++] * Reg[k];
     }
    FilteredSignal[j] = y;

    Top++;
    if(Top >= NumTaps)Top = 0;
   }
}

//void ProcessADCSamples(int * AdcBuffer)
//{
//	/* Do something with ADC Samples */ 
//    int indata;
//    int writedata;
//    for(writedata = 0; writedata < fftPoints; writedata++){
//        indata = *AdcBuffer++ - 2048;      //
//        inputData[writedata] = indata << 4;
//        if(writedata == fftPoints - 1){
//            FFT(inputData);
//            writedata = 0;
//        }
//    }
//}

void FFT(int * inputData)
{
    int	VFDdata[10];
    fractional VFD[10];
    int index = 0;
    int i;
    for(i = 0; i < fftPoints; i++) 
    {
        fftData[i].real = inputData[i];
        fftData[i].imag = 0;
    }

    FFTComplexIP( log2N, fftData, (fractcomplex *)twiddleFactors,(int) __builtin_psvpage(&twiddleFactors[0]));
    BitReverseComplex( log2N, fftData ); 
    
    
    SquareMagnitudeCplx( fftPoints, fftData, powerSpec ); 
    for(i=0;i<30;i++)
    {
        if((i%3)==2)
        {
            VFD[index] = (powerSpec[i] + powerSpec[i-1] + powerSpec[i-2]) / 3;
            index++;
        }
    }
    
    for(index=0;index<10;index++)
    {
        if(VFD[index]>0x100)
            VFDdata[index] = 0;
        else if(VFD[index] > 0xDC)
            VFDdata[index] = 1;
        else if(VFD[index] > 0xB8)
            VFDdata[index] = 2;
        else if(VFD[index] > 0x94)
            VFDdata[index] = 3;
        else if(VFD[index] > 0x70)
            VFDdata[index] = 4;
        else if(VFD[index] > 0x4C)
            VFDdata[index] = 5;
        else if(VFD[index] > 0x28)
            VFDdata[index] = 6;
        else
            VFDdata[index] = 7;
    }
    
    VFDbar(VFDdata,1);
    
//	/* Find the frequency Bin ( = index into the SigCmpx[] array) that has the largest energy*/
//	/* i.e., the largest spectral component */
//	VectorMax(fftPoints/2, powerSpec, &peakFrequencyBin);
//	/* Compute the frequency (in Hz) of the largest spectral component */
//	peakFrequency = peakFrequencyBin*(SAMPLING_RATE/fftPoints);
    i = 0;
}

void initAdc1(void)
{
		AD1CON1bits.FORM   = 3;		// Data Output Format: Signed Fraction (Q15 format)
		AD1CON1bits.SSRC   = 2;		// Sample Clock Source: GP Timer starts conversion
		AD1CON1bits.ASAM   = 1;		// ADC Sample Control: Sampling begins immediately after conversion
		AD1CON1bits.AD12B  = 0;		// 10-bit ADC operation
	

		AD1CON2bits.ALTS=1;			// Alternate Input Sample Mode Select Bit
		AD1CON2bits.CHPS  = 0;		// Converts CH0

		AD1CON3bits.ADRC = 0;		// ADC Clock is derived from Systems Clock
		AD1CON3bits.ADCS = 63;		// ADC Conversion Clock Tad=Tcy*(ADCS+1)= (1/9M)*64 = 1.6us (140.625Khz)
									// ADC Conversion Time for 10-bit Tc=12*Tab = 

		AD1CON1bits.ADDMABM = 0; 	// DMA buffers are built in scatter/gather mode
		AD1CON2bits.SMPI    = 0;	// SMPI Must be programmed to 1 for this case
		AD1CON4bits.DMABL   = 6;	// Each buffer contains 64 words

        //AD1CHS0: A/D Input Select Register
        AD1CHS0bits.CH0SA = 10;		// MUXA +ve input selection (AIN10) for CH0
		AD1CHS0bits.CH0NA=0;		// MUXA -ve input selection (Vref-) for CH0
        AD1CSSLbits.CSS10 = 1;   // select AN10 for input scan
        
//      AD1CHS0bits.CH0SB=10;		// MUXB +ve input selection (AIN5) for CH0
//		AD1CHS0bits.CH0NB=0;		// MUXB -ve input selection (Vref-) for CH0
				
        //AD1PCFGH/AD1PCFGL: Port Configuration Register
	//	AD1PCFGL=0xFFFF;
	//	AD1PCFGH=0xFFFF;
        AD1PCFGLbits.PCFG10 = 0;		// AN10 as Analog Input
    //  AD1PCFGLbits.PCFG10 = 0;		// AN5 as Analog Input		
        
        IFS0bits.AD1IF = 0;			// Clear the A/D interrupt flag bit
        IEC0bits.AD1IE = 0;			// Do Not Enable A/D interrupt 
        AD1CON1bits.ADON = 1;		// Turn on the A/D converter	


}

void InitSPI(void) 
{
    SPI1CON1bits.DISSCK = 0; //SCK pin is controlled by SPI module
    SPI1CON1bits.DISSDO = 0; //SDO pin is controlled by SPI module
    SPI1CON1bits.MODE16 = 0; //8-bit mode selected
    SPI1CON1bits.SMP = 0; //sample data in midle of data output time
    SPI1CON1bits.CKE = 1; //positive clock edge selected
    SPI1CON1bits.SSEN = 0; //master mode, SS pin is not used
    SPI1CON1bits.CKP = 0; //clock active high
    SPI1CON1bits.MSTEN = 1; //select master mode
    SPI1CON1bits.SPRE = 0b101; //secondary scale 1:4
    SPI1CON1bits.PPRE = 0b11; //primary scale 1:1
    SPI1STATbits.SPIROV = 0; //clear overflow flag
    SPI1STATbits.SPIEN = 1; //enable SPI module; config SDI, SDO, SCK pins
    SPI1STATbits.SPISIDL = 0; //halt the module in idle state
    SPI1STATbits.SPITBF = 0; //clear TX buffer full flag
    SPI1STATbits.SPIRBF = 0; //clear RX buffer full flag
    
    SPI2CON1bits.DISSCK = 0; //SCK pin is controlled by SPI module
    SPI2CON1bits.DISSDO = 0; //SDO pin is controlled by SPI module
    SPI2CON1bits.MODE16 = 0; //8-bit mode selected
    SPI2CON1bits.SMP = 0; //sample data in midle of data output time
    SPI2CON1bits.CKE = 1; //positive clock edge selected
    SPI2CON1bits.SSEN = 0; //master mode, SS pin is not used
    SPI2CON1bits.CKP = 0; //clock active high
    SPI2CON1bits.MSTEN = 1; //select master mode
    SPI2CON1bits.SPRE = 0b101; //secondary scale 1:4
    SPI2CON1bits.PPRE = 0b11; //primary scale 1:1
    SPI2STATbits.SPIROV = 0; //clear overflow flag
    SPI2STATbits.SPIEN = 1; //enable SPI module; config SDI, SDO, SCK pins
    SPI2STATbits.SPISIDL = 0; //halt the module in idle state
    SPI2STATbits.SPITBF = 0; //clear TX buffer full flag
    SPI2STATbits.SPIRBF = 0; //clear RX buffer full flag
}


      
void InitClock()
{
    PLLFBD = 4;  //
    CLKDIVbits.PLLPOST = 0;    // N1 = 2
    CLKDIVbits.PLLPRE = 0;    // N2 = 2
    OSCTUN = 0;
    RCONbits.SWDTEN = 0;
    // Clock switch to incorporate PLL    NOSC = 0b010
    __builtin_write_OSCCONH(0b011);
    __builtin_write_OSCCONL(0b001);    // Start clock switching
    while (OSCCONbits.COSC != 0b011);    // Wait for Clock switch to occur    
    while(OSCCONbits.LOCK != 1) {};
}

void Init_Timer1(void)
{
    T1CONbits.TON = 0;     // Disable Timer
    T1CONbits.TCS = 0;     // Select internal instruction cycle clock
    T1CONbits.TGATE = 0;   // Disable Gated Timer mode
    T1CONbits.TCKPS = 0b10;// Select 1:64 Prescaler

    TMR1 = 0x00;           // Clear timer register
    PR1 = 164;            

    IPC0bits.T1IP = 0x01;  // Set Timer1 Interrupt Priority Level
    IFS0bits.T1IF = 0;     // Clear Timer1 Interrupt Flag
    IEC0bits.T1IE = 1;     // Enable Timer1 interrupt
    T1CONbits.TON = 1;
}

void Init_Timer2(void)
{
    T2CONbits.TON = 0;     // Disable Timer
    T2CONbits.TCS = 0;     // Select internal instruction cycle clock
    T2CONbits.TGATE = 0;   // Disable Gated Timer mode
    T2CONbits.TCKPS = 0b11;// Select 1:256 Prescaler

    TMR2 = 0x00;           // Clear timer register
    PR2 = 2000;            

    IPC1bits.T2IP = 0x05;  // Set Timer2 Interrupt Priority Level
    IFS0bits.T2IF = 0;     // Clear Timer2 Interrupt Flag
    IEC0bits.T2IE = 1;     // Enable Timer2 interrupt
    T2CONbits.TON = 1;
}


void initTmr3() 
{
//        TMR3 = 0x0000;
//        PR3 = 17578;
//        IFS0bits.T3IF = 0;
//        IEC0bits.T3IE = 0;
//
//        //Start Timer 3
//        T3CONbits.TON = 1;
    
    T3CONbits.TON = 0;        // Disable Timer
    T3CONbits.TCS = 0;        // Select internal instruction cycle clock
    T3CONbits.TGATE = 0;      // Disable Gated Timer mode
    //T3CONbits.TCKPS = 0b11;   // Select 1:256 Prescaler

    TMR3 = 0x00;           // Clear timer register
    PR3 =17578;            

    IPC2bits.T3IP = 0x5;  // Set Timer2 Interrupt Priority Level
    IFS0bits.T3IF = 0;     // Clear Timer2 Interrupt Flag
    IEC0bits.T3IE = 1;     // Enable Timer2 interrupt
    T3CONbits.TON = 1;

}


void initDma0(void)
{
	DMA0CONbits.AMODE = 2;			// Configure DMA for Peripheral indirect mode
	DMA0CONbits.MODE  = 2;			// Configure DMA for Continuous Ping-Pong mode
	IPC1bits.DMA0IP = 1;
    
	DMA0PAD=(int)&ADC1BUF0;
	DMA0CNT = (SAMP_BUFF_SIZE*2)-1;					

	DMA0REQ=13;

	DMA0STA = __builtin_dmaoffset(BufferA);		
	//DMA0STB = __builtin_dmaoffset(BufferB);

	IFS0bits.DMA0IF = 0;			//Clear the DMA interrupt flag bit
    IEC0bits.DMA0IE = 1;			//Set the DMA interrupt enable bit
    IPC1bits.DMA0IP = 4;
	DMA0CONbits.CHEN=1;

}
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

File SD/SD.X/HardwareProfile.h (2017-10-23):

/******************************************************************************
 *
 *                Microchip Memory Disk Drive File System
 *
 ******************************************************************************
 * FileName:        HardwareProfile.h
 * Dependencies:    None
 * Processor:       PIC18/PIC24/dsPIC30/dsPIC33/PIC32
 * Compiler:        C18/C30/C32
 * Company:         Microchip Technology, Inc.
 *
 * Software License Agreement
 *
 * The software supplied herewith by Microchip Technology Incorporated
 * (the ?Company?) for its PICmicro® Microcontroller is intended and
 * supplied to you, the Company?s customer, for use solely and
 * exclusively on Microchip PICmicro Microcontroller products. The
 * software is owned by the Company and/or its supplier, and is
 * protected under applicable copyright laws. All rights are reserved.
 * Any use in violation of the foregoing restrictions may subject the
 * user to criminal sanctions under applicable laws, as well as to
 * civil liability for the breach of the terms and conditions of this
 * license.
 *
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
*****************************************************************************/


#ifndef _HARDWAREPROFILE_H_
#define _HARDWAREPROFILE_H_

// Define your clock speed here

// Sample clock speed for PIC18
#if defined (__18CXX)

    #define GetSystemClock()        40000000                        // System clock frequency (Hz)
    #define GetPeripheralClock()    GetSystemClock()                // Peripheral clock freq.
    #define GetInstructionClock()   (GetSystemClock() / 4)          // Instruction clock freq.

// Sample clock speed for a 16-bit processor
#elif defined (__C30__)

    #define GetSystemClock()        32000000
    #define GetPeripheralClock()    GetSystemClock()
    #define GetInstructionClock()   (GetSystemClock() / 2)

    // Clock values
    #define MILLISECONDS_PER_TICK       10                      // Definition for use with a tick timer
    #define TIMER_PRESCALER             TIMER_PRESCALER_8       // Definition for use with a tick timer
    #define TIMER_PERIOD                20000                   // Definition for use with a tick timer

// Sample clock speed for a 32-bit processor
#elif defined (__PIC32MX__)

    // Indicates that the PIC32 clock is running at 48 MHz
    //#define RUN_AT_48MHZ
    // Indicates that the PIC32 clock is running at 24 MHz
    //#define RUN_AT_24MHZ
    // Indicates that the PIC32 clock is running at 60 MHz
    #define RUN_AT_60MHZ

    // Various clock values

    #if defined(RUN_AT_48MHZ)
        #define GetSystemClock()            48000000UL              // System clock frequency (Hz)
        #define GetPeripheralClock()        48000000UL              // Peripheral clock frequency
        #define GetInstructionClock()       (GetSystemClock())      // Instruction clock frequency
    #elif defined(RUN_AT_24MHZ)
        #define GetSystemClock()            24000000UL
        #define GetPeripheralClock()        24000000UL
        #define GetInstructionClock()       (GetSystemClock())
    #elif defined(RUN_AT_60MHZ)    
        #define GetSystemClock()            (60000000ul)
        #define GetPeripheralClock()        (GetSystemClock()) 
        #define GetInstructionClock()       (GetSystemClock())
    #else
        #error Choose a speed
    #endif

    // Clock values

    #define MILLISECONDS_PER_TICK       10                  // Definition for use with a tick timer
    #define TIMER_PRESCALER             TIMER_PRESCALER_8   // Definition for use with a tick timer
    #define TIMER_PERIOD                37500               // Definition for use with a tick timer
#endif
    




// Select your interface type
// This library currently only supports a single physical interface layer at a time


// Description: Macro used to enable the SD-SPI physical layer (SD-SPI.c and .h)
#define USE_SD_INTERFACE_WITH_SPI

// Description: Macro used to enable the CF-PMP physical layer (CF-PMP.c and .h)
//#define USE_CF_INTERFACE_WITH_PMP

// Description: Macro used to enable the CF-Manual physical layer (CF-Bit transaction.c and .h)                                                                
//#define USE_MANUAL_CF_INTERFACE

// Description: Macro used to enable the USB Host physical layer (USB host MSD library)
//#define USE_USB_INTERFACE


/*********************************************************************/
/******************* Pin and Register Definitions ********************/
/*********************************************************************/

/* SD Card definitions: Change these to fit your application when using
   an SD-card-based physical layer                                   */
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

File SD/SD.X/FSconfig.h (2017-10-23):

/******************************************************************************
 *
 *                Microchip Memory Disk Drive File System
 *
 ******************************************************************************
 * FileName:        FSconfig.h
 * Dependencies:    None
 * Processor:       PIC18/PIC24/dsPIC30/dsPIC33
 * Compiler:        C18/C30
 * Company:         Microchip Technology, Inc.
 * Version:         1.0.0
 *
 * Software License Agreement
 *
 * The software supplied herewith by Microchip Technology Incorporated
 * (the ?Company?) for its PICmicro® Microcontroller is intended and
 * supplied to you, the Company?s customer, for use solely and
 * exclusively on Microchip PICmicro Microcontroller products. The
 * software is owned by the Company and/or its supplier, and is
 * protected under applicable copyright laws. All rights are reserved.
 * Any use in violation of the foregoing restrictions may subject the
 * user to criminal sanctions under applicable laws, as well as to
 * civil liability for the breach of the terms and conditions of this
 * license.
 *
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
*****************************************************************************/


#ifndef _FS_DEF_

#include "HardwareProfile.h"

/***************************************************************************/
/*   Note:  There are likely pin definitions present in the header file    */
/*          for your device (SP-SPI.h, CF-PMP.h, etc).  You may wish to    */
/*          specify these as well                                          */
/***************************************************************************/

// The FS_MAX_FILES_OPEN #define is only applicable when Dynamic
// memeory allocation is not used (FS_DYNAMIC_MEM not defined).
// Defines how many concurent open files can exist at the same time.
// Takes up static memory. If you do not need to open more than one
// file at the same time, then you should set this to 1 to reduce
// memory usage
#define FS_MAX_FILES_OPEN 	3
/************************************************************************/

// The size of a sector
// Must be 512, 1024, 2048, or 4096
// 512 bytes is the value used by most cards
#define MEDIA_SECTOR_SIZE 		512
/************************************************************************/



/* *******************************************************************************************************/
/************** Compiler options to enable/Disable Features based on user's application ******************/
/* *******************************************************************************************************/


// Uncomment this to use the FindFirst, FindNext, and FindPrev
#define ALLOW_FILESEARCH
/************************************************************************/
/************************************************************************/

// Comment this line out if you don't intend to write data to the card
#define ALLOW_WRITES
/************************************************************************/

// Comment this line out if you don't intend to format your card
// Writes must be enabled to use the format function
//#define ALLOW_FORMATS
/************************************************************************/

// Uncomment this definition if you're using directories
// Writes must be enabled to use directories
#define ALLOW_DIRS
/************************************************************************/

// Allows the use of FSfopenpgm, FSremovepgm, etc with PIC18
#if defined(__18CXX)
    #define ALLOW_PGMFUNCTIONS
#endif
/************************************************************************/

// Allows the use of the FSfprintf function
// Writes must be enabled to use the FSprintf function
//#define ALLOW_FSFPRINTF
/************************************************************************/

// If FAT32 support required then uncomment the following
#define SUPPORT_FAT32
/* ******************************************************************************************************* */




// Select how you want the timestamps to be updated
// Use the Real-time clock peripheral to set the clock
// You must configure the RTC in your application code
//#define USEREALTIMECLOCK
// The user will update the timing variables manually using the SetClockVars function
// The user should set the clock before they create a file or directory (Create time),
// and before they close a file (last access time, last modified time)
//#define USERDEFINEDCLOCK
// Just increment the time- this will not produce accurate times and dates
#define INCREMENTTIMESTAMP


#ifdef USE_PIC18
	#ifdef USEREALTIMECLOCK
		#error The PIC18 architecture does not have a Real-time clock and calander module
	#endif
#endif

#ifdef ALLOW_PGMFUNCTIONS
	#ifndef USE_PIC18
		#error The pgm functions are unneccessary when not using PIC18
	#endif
#endif
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

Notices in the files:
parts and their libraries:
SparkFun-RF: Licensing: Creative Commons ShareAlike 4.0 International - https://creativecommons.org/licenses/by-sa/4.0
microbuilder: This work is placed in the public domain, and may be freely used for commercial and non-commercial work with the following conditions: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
